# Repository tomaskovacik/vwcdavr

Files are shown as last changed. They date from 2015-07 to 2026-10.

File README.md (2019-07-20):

radio_emulator: arduino (ATMEGAX8 boards only) based vw/audi/skoda/seat radio emulator, I made this to revers eng. on vwcdpic and improve arduino version of CDchanger

 - emulate RADIO DataOut signal
 - receive and print CD changer responce to serial console

serial output is 9600

commands:
 
- next track button       =
- previous track button   -
- next CD                 ]
- previous CD             [
- play/stop               p
- CD1                     1
- CD2                     2
- CD3                     3
- CD4                     4
- CD5                     5
- CD6                     6
- seek forward            f
- seek rewind             r
- scan mode               s
- shuffle mode            l
- help                    h
 
connectios:

- DataOut -> arduino pin 12

- Clk     -> arduino pin 3

- DataIn  -> arduino pin 4 

CDC_emulator: arduino based cd changer emulator for vw/audi/skoda/seat radios, based on avr port of vwcdpic(see header of file for more info)

current status (see readme inside dir):
- tested with my old audi concert 1 radio
- version for 2 8bit timers, has, but if it still works is questionable:
- ARDUINO headphones support
- ARDUINO headphones single button support
- bluetooth support for modules with AT commands (ovc3860 based: XS3868, S3860M-S, BLK-MD-SPK-B), BK8000L - one way only, no feedback from module - TODO

vw_cd_changer_sniffer - sniffer for radio comunication

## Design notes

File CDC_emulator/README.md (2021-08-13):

Little talk/history: http://kovo-blog.blogspot.sk/2014/02/cd-changer-emulator.html

CDC_emulator: Arduino based CD changer emulator for VW/Audi/Skoda/Seat radios, based on AVR port of vwcdpic (see header of file for more info)

- Android headphones three button support, with cdc_arduino_ported_k9spud_vwcdpic_headphone_support (thx @domnulvlad)
- Android headphones single button support - dropped (if you wanna have this, take a look at history of .ino files and make patch, I do not have time to test this...)
- Bluetooth support for modules with serial comunication, not fully implemented yet 

port_of_shyd_version_for_mpd:
	Arduino port of SHYD version of his emulator, currently not used by me anymore ( http://dev.shyd.de/2013/09/avr-raspberry-pi-vw-beta-vag-cdc-faker/ )

cdc_arduino_ported_k9spud_vwcdpic:
- Arduino Uno/Duemilanove/Nano AVR port of vwcdpic project, initial work: http://forums.hackaday.com/viewtopic.php?f=3&t=123
- support for: ATmega328, ATmega328A, ATmega328P, ATmega328PA, ATmega324, ATmega324P, ATmega324A, ATmega324PA
- original vwcdpic PJRC controler support
- full SHYD mpd control support
- minimal Bluetooth support for BT with serial control support
- timer1 is used for timing incomming control data from radio pin DataOut, timer interrupt (ICP) is used
- timer2 is used for timing between pakcets and also 800us gap between bytes in packet
- timer0 is used for 10ms timing used for 50ms timing between packets and also for 1second count for play time count
- software serial us used to comunicate with BT over serial

Connections are defined by these defines:

for ATmegaXX8YY chips:
```
#define RADIO_COMMAND      PB0 //ICP
#define RADIO_COMMAND_DDR  DDRB
#define RADIO_COMMAND_PORT  PORTB
#define RADIO_COMMAND_PIN PINB
#define RADIO_CLOCK        PB5
#define RADIO_CLOCK_DDR    DDRB
#define RADIO_CLOCK_PORT  PORTB
#define RADIO_DATA         PB3
#define RADIO_DATA     DDB3
#define RADIO_DATA_DDR     DDRB
#define RADIO_DATA_PORT  PORTB
```

in Arduino world, it is:
```
 * RADIO PIN -> Arduino pin
 * 
 * DataOut   -> digital 8 (ICP1)
 * DataIn    -> digital 11(PB3)
 * Clock     -> digital 13(PB5)
 *
 * computer -> Arduino pin
 * serial TX -> digital 0 (PD0)
 * serial RX -> digital 1 (PD1)
```

for ATmegaXX4YY chips:
```
#define RADIO_COMMAND      PD6 //ICP 
#define RADIO_COMMAND_DDR  DDRD
#define RADIO_COMMAND_PORT  PORTD
#define RADIO_COMMAND_PIN PIND
#define RADIO_CLOCK        PB7
#define RADIO_CLOCK_DDR    DDRB
#define RADIO_CLOCK_PORT  PORTB
#define RADIO_DATA         PB5
#define RADIO_DATA_DDR     DDRB
#define RADIO_DATA_PORT  PORTB
```

in Arduino world, if my board is used (https://www.tindie.com/products/tomaskovacik/nanoxx4/) then this traslate to:
```
 * RADIO PIN -> Arduino pin
 *
 * DataOut   -> digital 8 (ICP1)
 * DataIn    -> digital 11(PB5)
 * Clock     -> digital 13(PB7)
 *
 * computer -> Arduino pin
 * serial TX -> digital 0 (PD0)
 * serial RX -> digital 1 (PD1)
```

cdc_arduino_ported_k9spud_vwcdpic_headphone_support:
- Support for: ATmega328, ATmega328A, ATmega328P, ATmega328PA, ATmega324, ATmega324P, ATmega324A, ATmega324PA
- Android three button headphones support or MP3 player buttons support
- Tested on Arduino Uno (ATmega328P)
- For more info, check the comment at the top of the file

Connections:
```
   UNO, Duemilanove, Nano ... ATmegaX8 base boards:
   RADIO PIN -> Arduino pin

   DataOut   -> digital 8 (PB0)
   DataIn    -> digital 11(PB5)
   Clock     -> digital 13(PB7)

   PC PIN    -> Arduino pin
   Serial TX -> digital 0 (PD0)
   Serial RX -> digital 1 (PD1)
   
   ANDROID support:
   NEXT button -> digital 5 (PD5)
   PLAY button -> digital 6 (PD6)
   PREV button -> digital 7 (PD7)
```

cdc_arduino_ported_k9spud_vwcdpic_just_8bit_timers:
same as previous, but use 2 8bit timers, mostly for ATTINY chips 
 - tested on ATmega328, ATmega8, ATtiny85
 - with ATtiny85 chip only serial output is used, no input (using tinydebug serial @ 9600) - BT support posible only if BT chip has default baudrate set to 9600
 - this version has support to control Android headphone simulating buttons on headphone jack (I do not remember if I tested it or not, sorry), also has single button support (single, double, triple click)

Connections:
```
   UNO, Duemilanove, Nano ... ATmegaX8 base boards:
   RADIO PIN -> Arduino pin

   DataOut   -> digital 2 (INT0)
   DataIn    -> digital 11(PB3)
   Clock     -> digital 13(PB5)

   PC PIN    -> Arduino pin
   Serial TX -> digital 0 (PD0)
   Serial RX -> digital 1 (PD1)

   ANDROID support:
   PREVIOUS BUTTON -> digital 7 (PD7)
   PLAY BUTTON -> digital 6 (PD6)
   NEXT BUTTON -> digital 5 (PD5)

   ATTINYx5 version:

   RADIO PIN -> ATTINYx5 PIN
   DataOut   -> 7 (INT0)
   DataIn    -> 6 (PB0)
   Clock     -> 5 (PB1)

   PC PIN    -> ATTINYx5 PIN
   Serial TX -> 2 (PB3) using tinydebug lib
   Serial RX -> not connected
```

   What you need to install:
   ATTinycore: https://github.com/SpenceKonde/ATTinyCore (supported directly in Arduino from version 1.6.3 via board manager)
   TinyDebugSerial from: https://github.com/jscrane/TinyDebugSerial (download and extract into libraries Arduino folder)

   select attiny25/45/85 board from tools-> board -> (ATTinyCore) ATtiny25/45/85
   select attiny85 from tools->chip->ATtiny85
   select internal 8Mhz from tools->Clock -> 8MHz (internal)

   to use digispark uncoment line //#define DIGISPARK
   then use 16MHz-noUSB settings 
   tested only with my ATTinyCore fork with Digispark support: https://github.com/tomaskovacik/ATTinyCore/

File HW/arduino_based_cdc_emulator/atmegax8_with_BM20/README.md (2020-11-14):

interactive bom:

https://tomaskovacik.github.io/vwcdavr/HW/arduino_based_cdc_emulator/atmegax8_with_BM20/bom01/ibom.html

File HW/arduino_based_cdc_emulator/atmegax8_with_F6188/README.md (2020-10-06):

link to ibom file on github.io pages:

https://tomaskovacik.github.io/vwcdavr/HW/arduino_based_cdc_emulator/atmegax8_with_F6188/bom/ibom.html

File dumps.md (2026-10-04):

## Dump pattern notes

Source files:
- `dumps/dump_cdc_real_changer.txt`
- `dumps/dump_cdc_real_changer_real_radio_audi_concert1.txt`

## Protocol encoding

CDC status packets are 8 bytes sent from the changer to the head unit over a clocked serial
bus.  The data line uses negative/inverted NRZ logic: a code bit of 0 drives the wire HIGH
and a code bit of 1 drives it LOW.  The sniffer reads pin-HIGH as 1, so the captured
(dump) byte equals `code_byte XOR 0xFF`.  Equivalently: `code_byte = dump_byte XOR 0xFF`.

### 8-byte packet layout (wire/dump values)

| Byte | Field | Notes |
|---|---|---|
| 0 | Frame start | Encodes state & ACK; emulator varies this by state |
| 1 | Disc | `disc_number = dump_byte XOR 0xBF`  (CD1=0x01, CD2=0x02 …) |
| 2 | Track | `track_number = dump_byte XOR 0xFF` |
| 3 | Minute | `minute = dump_byte XOR 0xFF` |
| 4 | Second | `second = dump_byte XOR 0xFF` |
| 5 | Scan/Mix flags | bit 5 (code) = Mix, bit 4 (code) = Scan; 0x00→wire 0xFF = no flags |
| 6 | Mute/State | Controls audio mute and player state (see below) |
| 7 | Frame end | Mirrors frame start state encoding |

### 4-byte radio command layout

| Byte | Value  | Notes |
|---|---|---|
| 1 | `0x53` | fixed header |
| 2 | `0x2C` | fixed header |
| 3 | cmd | command code, always a multiple of 4 |
| 4 | ~cmd | bitwise complement of byte 3 |

## Packet structure patterns

- Head unit command packets follow:
  - byte1 `0x53`
  - byte2 `0x2C`
  - byte3 command code
  - byte4 bitwise complement of byte3
- Frequent trailer/control command:
  - `532C14EB` appears very often (end command / next-cd follow-up behavior).

## Common command patterns from dumps

- Enable/disable:
  - `532CE41B` (ENABLE, common in one dump)
  - `532C08F7` (ENABLE MK, very common with Audi Concert 1 dump)
  - `532C10EF` (DISABLE)
- Navigation and mode:
  - `532C38C7` (SEEKFORWARD MK / inquiry-like transition)
  - `532CD827` (seek forward)
  - `532C58A7` (seek back)
  - `532C609F` / `532CE01F` (mix variants)
  - `532CA05F` (scan)
  - `532C30CF` (TP)

## State packets: emulator vs real changer comparison

The second dump (`dump_cdc_real_changer_real_radio_audi_concert1.txt`) contains captures
from both a real 6-disc changer and from the Arduino emulator (captured in different
sessions and concatenated).  Patterns with frame byte `0x34`/`0x3C` originate from the
emulator; patterns with `0xB4`/`0xBC` originate from the real changer.

### Idle state

| Source | Wire packet | Mute byte |
|---|---|---|
| Emulator | `74 BE FE FF FF FF 8F 7C` | `0x8F` |
| Real changer  | `B4 BF FF FF FF FF 8F BC` | `0x8F` |

**Mute byte matches (`0x8F`, code `0x70`).**  The frame bytes differ — the real changer
uses frame `0xB4`/`0xBC` for all states (constant), while the emulator changes the frame
byte per state.  Both are accepted by tested head units.

Disc byte: real changer starts at disc `0` (`0xBF`); emulator starts at disc `1` (`0xBE`).
This difference is cosmetic on head units that accept the first valid PLAY command.

### Play state

| Source | Wire packet | Mute byte | Frame |
|---|---|---|---|
| Emulator | `34 BE FE FF FF FF CF 3C` | `0xCF` | `34`/`3C`|
| Real changer  | `B4 BE FE FF FF FF 6F BC` | `0x6F` | `B4`/`BC`|

Differences:
- **Frame byte**: emulator `0x34`/`0x3C` (code `0xCB`/`0xC3`), real `0xB4`/`0xBC`
  (code `0x4B`/`0x43`).
- **Mute byte**: emulator `0xCF` (code `0x30`), real `0x6F` (code `0x90`).
  Bit 7 of the code differs: code `0x90 = 1001 0000` vs `0x30 = 0011 0000`.
  The comment in the code notes code `0x70` (wire `0x8F`) "mutes audio on Monsoon head
  units" during idle.  The real changer uses code `0x90` for play, which differs from both
  the emulator's play value (`0x30`) and the idle mute value (`0x70`).  The emulator is
  accepted by most tested head units with code `0x30`, but code `0x90` may be more
  compatible with Monsoon-type head units that use this byte for mute control.

### Disc announcement packets (during init/load)

During `StateInitPlay` the emulator sends disc-slot info bytes cycling from `0xD1` to
`0xD6` (wire `0x2E` to `0x29`).  These match the real changer's announce packets seen in
the dumps (e.g. `B4 2E 0 FF FF FF FF BC`, `B4 2D 0 FF FF ...`).  Encoding is correct.

## Response/frame behavior patterns

- Real changer streams repeated 8-byte status/display frames between command events.
- Around SCAN events, mode/status bytes often move to values consistent with scan flag
  enabled (for example, lines in the dump files that include `... EF ...` inside the
  8-byte response frame text).
- Dumps also show many interleaved, partially corrupted/noisy rows (capture timing/noise),
  so stable interpretation depends on repeated motifs rather than single lines.

## Code issues found during analysis

### Fixed bugs

1. **`cdButtonPushed` case 6 (functions.ino)**: case 6 incorrectly reset and returned
   `cd5pushed` instead of `cd6pushed`.  Fixed in the main variant.

2. **`Do_CD2` calls wrong argument (main .ino)**: `Do_CD2` called `cdButtonPushed(1)`
   instead of `cdButtonPushed(2)`, silently counting CD1 presses when CD2 is pressed.
   Fixed in the main variant.

3. **ATmega8 ISR assignment instead of comparison (main .ino, BK3254 variant)**: the
   ATmega8 `TIMER0_OVF` ISR used `=` (assignment) instead of `==` (comparison):
   ```c
   // BUG (before fix):
   if (counter_timer0_overflows = _TIMER0_OVERFLOW_COUNTS)
   // FIXED:
   if (counter_timer0_overflows == _TIMER0_OVERFLOW_COUNTS)
   ```
   With the assignment, `flag_50ms` fired on every overflow instead of every 50 ms,
   making the 50 ms timer fire ~50× too fast on ATmega8/ATmega128 targets.

### Noted discrepancies (not changed)

- **Play state mute byte**: emulator uses code `0x30` (wire `0xCF`); real changer uses
  code `0x90` (wire `0x6F`).  Most head units accept `0xCF`, but if audio stays muted
  during playback on a Monsoon-type head unit, changing `SendByte(0x30)` to
  `SendByte(0x90)` in `StatePlay` may help.
- **Frame bytes**: emulator encodes state in the frame byte (idle `0x8B`/`0x83`, play
  `0xCB`/`0xC3`); real changer uses a fixed frame byte (`0x4B`/`0x43`) for all states.
  This difference has not caused compatibility problems with tested radios.

## Practical implication for emulator tuning

- The strongest repeatable pattern tied to audible issues is SCAN-mode signaling.
- Suppressing SCAN indicator in emulator status packets is a reasonable first mitigation to test while keeping normal command parsing/ACK behavior.

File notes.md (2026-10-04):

## CDC emulator scan/mute test notes

### Context
- Investigated `CDC_emulator/cdc_arduino_ported_k9spud_vwcdpic` protocol handling and dumps in `dumps/`.
- Login/command framing looks correct (`53 2C <cmd> <~cmd>` and command byte multiple-of-4 checks).

### Observed issue
- Some radios intermittently enter CD scanning behavior and mute audio when emulator is active.
- In code, SCAN command (`Do_SCAN`, `0xA0`) previously toggled the SCAN indicator bit (`0x10`) in outgoing display/status mode byte.

### Change in this PR
- For `Do_SCAN`, keep `scan = FALSE` so outgoing packets do not set SCAN indicator bit.
- Command is still accepted and acknowledged; only scan-indicator signaling is suppressed.

### Why
- Dump patterns show real radios issuing SCAN-related commands, and historical comments in code already suggest scan signaling can cause mute on some units.
- This is a minimal risk change focused on avoiding the known mute path while preserving normal protocol flow.

### How to test
1. Flash updated sketch from `CDC_emulator/cdc_arduino_ported_k9spud_vwcdpic`.
2. Start playback and trigger operations that previously led to scan/mute (SCAN button, next/seek cycles, CD change).
3. Verify:
   - audio remains unmuted,
   - head unit still stays in CDC mode,
   - track/disc updates still work.
4. Compare with previous firmware if needed.

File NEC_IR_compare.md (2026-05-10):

# NEC IR Protocol vs VW CD-changer Protocol: Comparison

## Background

Investigation into whether an Arduino NEC IR library (e.g. IRremote, IRLib2) can replace the custom software used for the VW CD-changer (CDC) ↔ radio communication in this project.

## What the Custom SW Does

### TX (radio_emulator: Arduino pretends to be the radio, sends commands to CDC)

The `send_cmd()` / `shiftOutPulse()` functions in `radio_emulator.ino` manually bit-bang the DataOut line:

- 9 ms HIGH leader, 4.5 ms LOW space
- Each bit: 550 µs HIGH mark, then 540 µs (logic '0') or 1650 µs (logic '1') LOW space
- 4 bytes total per packet: `0x53 0x2C [cmd] [0xFF ^ cmd]`
- **Bit order: MSB first**

### RX (CDC emulator / sniffer: Arduino receives commands from real radio, responds as CDC)

The ISR in `cdc_arduino_ported_k9spud_vwcdpic.ino` uses Timer1 Input Capture to time LOW pulses on DataOut:

- Start bit: LOW > 3,200 µs
- Bit '1': LOW > 1,248 µs
- Bit '0': LOW > 256 µs
- Bits accumulated **MSB first** into a capture buffer

---

## Protocol Comparison Table

| Feature | NEC IR Library | VW Protocol | Compatible? |
|---|---|---|---|
| Leader mark | 9 ms | 9 ms | ✅ |
| Leader space | 4.5 ms | 4.5 ms | ✅ |
| Bit mark | 562.5 µs | ~550 µs (~2% off) | ✅ |
| Bit '0' space | 562.5 µs | ~540 µs (~4% off) | ✅ |
| Bit '1' space | 1687.5 µs | ~1650 µs (~2% off) | ✅ |
| Packet length | 32 bits | 32 bits | ✅ |
| **Bit order** | **LSB first** | **MSB first** | ❌ |
| Address validation | addr + ~addr = 0xFF | fixed 0x53 + 0x2C (0x53 + 0x2C ≠ 0xFF) | ❌ |
| Command validation | cmd + ~cmd = 0xFF | cmd + (0xFF ^ cmd) = 0xFF | ✅ |
| Physical medium | Modulated IR 38 kHz carrier → demodulator inverts signal | Direct wire (no carrier, no demodulation) | ❌ |
| Idle wire state | Library assumes demodulated: idle = HIGH | DataOut idle = LOW | ❌ |

---

## Analysis by Direction

### RX (receiving radio commands) — Feasible with adaptation

The timing tolerances of NEC libraries are typically ±20–30%, so the VW timing fits within NEC decoders. However, the following issues must be resolved:

1. **Polarity**: The VW DataOut wire is active-HIGH (mark = HIGH pulse), while an NEC demodulator output is active-LOW (mark = LOW = carrier present). The signal must be inverted — either via a transistor/NOT gate in hardware, or by configuring the library to use the opposite edge.
2. **Bit order**: After decoding, every received byte must be bit-reversed (`reverse_bits(byte)`) before use, since the library decodes LSB-first while the VW protocol is MSB-first.
3. **Address validation**: The library would decode `0x53 0x2C` as address + ~address, but `~0x53 = 0xAC ≠ 0x2C`, so **NEC address validation would reject all packets**. This check must be disabled or bypassed in the library.

### TX (sending radio commands) — Feasible with adaptation

Libraries like IRremote can send raw NEC timing. However:

1. **No IR carrier needed**: The 38 kHz carrier modulation must be disabled; the DataOut line must be driven directly.
2. **Bit order**: Each of the 4 bytes must be bit-reversed before passing to the library, or `sendRaw()` must be used with a manually constructed pulse array.
3. **Fixed address bytes**: The `0x53 0x2C` sync word must be sent as-is; a standard `sendNEC(address, command)` call would not produce the correct bit pattern without byte reversal.

---

## Practical Verdict

Using a standard NEC library **as-is will not work**. The protocol is close enough that it could be adapted **with the following modifications**:

1. **Hardware invert** the DataOut signal (one transistor or logic inverter between the Arduino pin and the VW bus).
2. **Bit-reverse** every byte before TX or after RX.
3. **Disable** NEC address-complement validation in the library's RX path.
4. For TX, use `sendRaw()` instead of `sendNEC()` to avoid the library imposing its own packet structure.

### Why the custom SW is preferred

The existing custom ISR-based approach is:
- Lean (~200 lines), no external dependencies
- Already verified against real hardware
- Handles the exact polarity, bit order, and sync-word format natively

A NEC library would add ~2–5 KB of flash, introduce 38 kHz carrier overhead that must be disabled, and still require all of the workarounds listed above. **The custom SW is the simpler and more reliable path for this use case.**

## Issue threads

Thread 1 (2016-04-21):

[Question] XS-3868 connect to arduino.

AYastrebov, 2016-04-21:
Hello, Tomas!

Nice work!
I've successfully flashed arduino pro mini and now have an AUX in my vw sony gamma 5.

I've purchased XS-3868 board and would like to use it in my system. But unfortunately, I can't figure out, which pins of XS-3868 should be connected to arduino board. Can you point me?

Thanks!

tomaskovacik, 2016-04-21:
Look in my hw repository. Kicad and there are modules with pinouts also schemarics for arduino and bluethooth

Sent from my Sony Xperia™ smartphone

---- Andrey Yastrebov wrote ----

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

Closed 2018-06-28.

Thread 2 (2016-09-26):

Atmega328

olii, 2016-09-26:
Does not work with Arduino nano(Atmega328) and Skoda Fabia Symphony.
I see data comming from head unit but on display it is "No CD Changer".

tomaskovacik, 2016-09-26:
I do not have skoda fabia with symphony.... but, which code? how you connect it to ? do you have pics ? did you connected it like  this https://github.com/tomaskovacik/hw/blob/master/kicad/arduino_based_cdc_emulator/connection_to_HU.png ?

olii, 2016-09-26:
no matter what project I used(https://github.com/tomaskovacik/vwcdavr/tree/master/CDC_emulator) , I read instructions in source how to connect to pins. As I wrote before, nano receives command from head unit, so I think connection is ok. However, Tx line on arduino(pin 13) is connected to LED, but I do not know if it can be the problem.

tomaskovacik, 2016-09-26:
Try vwcdpic if it's works if you can

Sent from my Sony Xperia™ smartphone

---- Oliver Nemček wrote ----

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

tomaskovacik, 2016-09-28:
hello, so I am on computer now, can you send me output of serial console of arduino? it should tel there if it understend what radio send to "changer" if there is problem it will not work. also pictures how do you wire it up please (idealy to my personal email adress). thats all I can do for you. Or I can send you one of wvcdpic units for free if it's works and you can try to fix vwcdavr code to works with skoda symphony?

olii, 2016-09-28:
I used this source I found somewhere at russian site. It works fine and that is all I want. I dont want advanced features, key  press, minutes and seconds ...

Maybe if you want, you can also use Spi library, because when I used my second arduino as logic analyzer, the output looked really bad. If I use this source, the output looks just fine.

Now I think I am going to build preamp from your scheme :)

https://gist.github.com/olii/56c874f41b649496672b34da8177ee7e

olii, 2016-09-28:
btw I think that emulator could decode radio commands, but radio couldnt because of some bug in the code

tomaskovacik, 2016-09-28:
if output look bad, that its problem with code/HW/freq, I will check it. Spi is ok when radio can handle the speed. I try it, but it's HW specific = not good for generic code which has to be ported to other mcus. Also code which you linked  work, but in some cases radio will not tolerate if you press button and cdchanger will not react as it should.

my be you did not configure it proparly. for basic functions you need to comment out mpd, bluetooth android stuff ...

just to clarify:
I'm not author of original C code, you can try original one, port it to arduino by your self and then tell me what I f*ck in it :) it will help other guys,  link is in coment of each code (www.mikrocontroller.net/attachment/31279/vwcdc.c).

Shyd version is just my port for shyd code for arduino, shyd version is what is on russian forum, just striped from other "mpd" stuff, or its my port of his work striped down.

tomaskovacik, 2018-06-29:
2ys inactivity, closing

kalabase, 2021-05-10:
after struggling for days mine finally went into CD Changer mode with Arduino IDE, UNO and a VW MK1 ZAR. thanks @tomaskovacik  if your have paypal for sponsor share link I can donate few bucks to show gratitude.
Next step is to connect audio signal
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

Closed 2018-06-29.

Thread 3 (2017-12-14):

Debugging 'dataerr' messages

justinvdk, 2017-12-14:
I've hooked up an Uno to my RCD 200. Everything seems to work okay (bit glitchy, but restarting radio + arduino usually does the trick).
To debug this I hooked up the serial monitor and it got spammed with `dataerr` messages.
Like so:
```
AudAudi Concert I Multimedia Gateway Ver.1.0c
RING
LIST2
80dataerr
Audi Concert I Multimedia Gateway Ver.1.0c
NEXT
LIST1
LIST2
dataerr
80Audi Concert I Multimedia Gateway Ver.1.0c
Audi Concert I Multimedia Gateway Ver.1.0c
Audi Concert I Multimedia Gateway Ver.1.0c
Audi Concert I Multimedia Gateway Ver.1.0c
LIST1
Audi Concert I Multimedia Gateway Ver.1.0c
LIST3
5300000000dataerr
LIST4
dataerr
80LIST5
400000dataerr
0000dataerr

```

Is this an actual error, or somewhat expected?

From the code the `dataerr` indicated a framing type data error, and also that "This should never happen on normal head unit sending 32 bit command strings with error free data".

I can't quite debug where the (seemingly) random numbers come from (`80`, `5300000000`, `400000`, etc). I.e. I can't find where in the code they are put into the txbuffer, via `EnqueueString` or otherwise.

Any ideas?

Ps. The CD / track buttons DO change the cd and track accordingly (cd1 - cd6 and TR01 - TR99).
Pps. Only thing hooked up are CLC, DATA_IN, DATA_OUT and ground. So without audio (Audio did work in a previous test, as long as the radio is in playing state, and I don't press buttons too quickly. If I do the radio stops playing).

EDIT:
I'm using the `cdc_arduino_ported_k9spud_vwcdpic_just_8bit_timers` version, I don't know if this matters

tomaskovacik, 2017-12-14:
hi, try regural version (without just_8bit_timers)..

regural version use 16bit timer, and also ICP1 which stopes timer and run ISR, 8bit version was originaly made to port it all to ATtiny85 mcus, it works but as you can see it need to by clean up or debug. there is lot of done in ISR ... which is not good as we know :)

more here:  http://kovo-blog.blogspot.sk/2015/06/vwcdpic-for-avr-arduino-and-attiny.html

justinvdk, 2017-12-14:
Ah I see. I figured that they would both work good and chose 8-bit only to have the 16-bit for myself to use (planning to interface with some other device).

Will try soon!

tomaskovacik, 2017-12-14:
bluetooth od dashboard ?:)

justinvdk, 2017-12-14:
I got a [SparkFun Purpletooth Jamboree](https://www.sparkfun.com/products/11924). I should be fine as it is possible to communicate over Serial.

I saw the TODO for AT commands, unfortunately I won't (can't) be helping with that :(

I WILL try to make it somewhat nice but I'm not very experienced in programming embedded stuff, so most is new to me.

justinvdk, 2017-12-14:
Switching to the "normal" version (with 16-bit timer) does not spew out errors (yay!).

But (for me, at least) the `capbuffer` isn't filled with anything (stays `000000000000000000000000`).

I can't investigate right now but will later. I'll close this issue as the original problem is not relevant anymore.

Closed 2017-12-14.

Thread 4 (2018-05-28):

arduino uno

JL01152, 2018-05-28:
I keep getting an error message of "PB0 was not declared in this scope." I am using an Arduino Uno and Arduino IDE I'm at a loss as to what the issue may be. Please Help.

tomaskovacik, 2018-05-28:
which sketch?

tomaskovacik, 2018-05-28:
I try all sketches in this repo, on arduino 1.8.5 everyone compile fine for arduino uno, closing

Closed 2018-05-28.

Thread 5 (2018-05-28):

Updated to Arduino 1.8.5 Still not compiling

JL01152, 2018-05-28:
Hi and thank you for your quick response. On my previous attempt I was using an outdated version of the Arduino IDE so I updated to 1.8.5 and now I'm getting the following error messages. This is for the  cdc_arduino_ported_k9spud_vwcdpic.ino file.

Arduino: 1.8.5 (Windows 7), Board: "Arduino/Genuino Uno"

C:\Users\WINDOW~1\AppData\Local\Temp\ccbR9Kq2.ltrans0.ltrans.o: In function `Init_VWCDC':

C:\Users\Windows7HD\Documents\cdc_arduino_ported_k9spud_vwcdpic/cdc_arduino_ported_k9spud_vwcdpic.ino:802: undefined reference to `ResetTime()'

C:\Users\Windows7HD\Documents\cdc_arduino_ported_k9spud_vwcdpic/cdc_arduino_ported_k9spud_vwcdpic.ino:804: undefined reference to `SetStateIdleThenPlay()'

C:\Users\Windows7HD\Documents\cdc_arduino_ported_k9spud_vwcdpic/cdc_arduino_ported_k9spud_vwcdpic.ino:813: undefined reference to `EnqueueString(unsigned char const*)'

C:\Users\Windows7HD\Documents\cdc_arduino_ported_k9spud_vwcdpic/cdc_arduino_ported_k9spud_vwcdpic.ino:815: undefined reference to `EnqueueString(unsigned char const*)'

C:\Users\Windows7HD\Documents\cdc_arduino_ported_k9spud_vwcdpic/cdc_arduino_ported_k9spud_vwcdpic.ino:817: undefined reference to `EnqueueString(unsigned char const*)'

C:\Users\Windows7HD\Documents\cdc_arduino_ported_k9spud_vwcdpic/cdc_arduino_ported_k9spud_vwcdpic.ino:819: undefined reference to `EnqueueString(unsigned char const*)'

C:\Users\Windows7HD\Documents\cdc_arduino_ported_k9spud_vwcdpic/cdc_arduino_ported_k9spud_vwcdpic.ino:856: undefined reference to `SendPacket()'

C:\Users\WINDOW~1\AppData\Local\Temp\ccbR9Kq2.ltrans0.ltrans.o: In function `main':

C:\Users\Windows7HD\Documents\cdc_arduino_ported_k9spud_vwcdpic/cdc_arduino_ported_k9spud_vwcdpic.ino:2156: undefined reference to `SetStateIdle()'

C:\Users\Windows7HD\Documents\cdc_arduino_ported_k9spud_vwcdpic/cdc_arduino_ported_k9spud_vwcdpic.ino:2183: undefined reference to `SetStatePlay()'

C:\Users\Windows7HD\Documents\cdc_arduino_ported_k9spud_vwcdpic/cdc_arduino_ported_k9spud_vwcdpic.ino:2190: undefined reference to `SetStateIdle()'

C:\Users\Windows7HD\Documents\cdc_arduino_ported_k9spud_vwcdpic/cdc_arduino_ported_k9spud_vwcdpic.ino:2206: undefined reference to `ResetTime()'

C:\Users\WINDOW~1\AppData\Local\Temp\ccbR9Kq2.ltrans0.ltrans.o: In function `CDC_Protocol':

C:\Users\Windows7HD\Documents\cdc_arduino_ported_k9spud_vwcdpic/cdc_arduino_ported_k9spud_vwcdpic.ino:1438: undefined reference to `SendPacket()'

C:\Users\Windows7HD\Documents\cdc_arduino_ported_k9spud_vwcdpic/cdc_arduino_ported_k9spud_vwcdpic.ino:1469: undefined reference to `EnqueueString(unsigned char const*)'

C:\Users\Windows7HD\Documents\cdc_arduino_ported_k9spud_vwcdpic/cdc_arduino_ported_k9spud_vwcdpic.ino:1471: undefined reference to `EnqueueString(unsigned char const*)'

C:\Users\Windows7HD\Documents\cdc_arduino_ported_k9spud_vwcdpic/cdc_arduino_ported_k9spud_vwcdpic.ino:1473: undefined reference to `EnqueueString(unsigned char const*)'

C:\Users\Windows7HD\Documents\cdc_arduino_ported_k9spud_vwcdpic/cdc_arduino_ported_k9spud_vwcdpic.ino:1529: undefined reference to `EnqueueString(unsigned char const*)'

C:\Users\Windows7HD\Documents\cdc_arduino_ported_k9spud_vwcdpic/cdc_arduino_ported_k9spud_vwcdpic.ino:1539: undefined reference to `EnqueueString(unsigned char const*)'

C:\Users\Windows7HD\Documents\cdc_arduino_ported_k9spud_vwcdpic/cdc_arduino_ported_k9spud_vwcdpic.ino:1545: undefined reference to `ScanCommandBytes()'

collect2.exe: error: ld returned 1 exit status

exit status 1
Error compiling for board Arduino/Genuino Uno.

This report would have more information with
"Show verbose output during compilation"
option enabled in File -> Preferences.

tomaskovacik, 2018-05-28:
please copy whole directory, not just one .ino file. functions.ino file is file which contain missing functions.

t.

JL01152, 2018-05-28:
Thanks a million. I was never gonna get that sorted. I successfully uploaded and will confirm functionality.
Closing.

Closed 2018-05-28.

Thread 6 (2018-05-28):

Cdc mode activated. No play function

JL01152, 2018-05-28:
I successfully compiled, uploaded and connected the arduino to audi symphony 2. It recognizes cdc1 track1 00:00 but does not emit sound from aux nor does it have play option. Is there sething I am missing?

tomaskovacik, 2018-05-28:
please comment out 85:
change
#define DISC_TRACK_NUMBER_FROM_MPD
to //#define DISC_TRACK_NUMBER_FROM_MPD

compile, upload and check what is on serial port please.

JL01152, 2018-05-28:
commented out line 85.

serial monitor:

Audi Concert I Multimedia Gateway Ver.1.0b
RING

JL01152, 2018-05-28:
solved by changing line 2156.

changed from SetStateIdle()
to SetStatePlay()
and it is working to play music from aux.

tomaskovacik, 2018-05-29:
thx! it should be probably used only with MPD control

t.

JL01152, 2018-05-30:
ok soi fried my arduino uno. I somehow shorted some pins while troubleshooting. I have uploaded the code to two different arduino pro minis and the unit does not change to cdc mode now when selecting CD.

Is there a way for me to confirm that I am receiving data from the headunit? Or are arduino pro minis incompatible?

Please help again.

JL01152, 2018-05-30:
i have 16mhz but i will check serial console. so far without unit powered upit keeps repeating the aforementioned messages without the RING.It did not do this with the uno

JL01152, 2018-06-07:
I found my issue. It turned out to be a wrong connection to the ground at the connector. The arduino would seem to power up and work properly but without the the ground it was never going to communicate with the unit. Thanks a million for your support. You are awesome.

Closed 2018-05-29.

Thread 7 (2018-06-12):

MPD Controls

JL01152, 2018-06-12:
Ok so I have been messing with the headphone jack on my galaxy s7 edge and I found that I can control the NEXT PREV PLAY/PAUSE functions with just shorting the the MIC ring to the GND ring.

Simulating Button Clicks (shorting to GND)
1 click = play/pause
2 quick clicks = NEXT track
3 quick clicks = PREV track
A 680ohm resistor to gnd simulates pressing the volume down key. ( Media if playing music, Ringtone volume if not playing music)

I have yet to find what other resistance values will do. I will try to incorporate these functions using a HEF4066 switch. Hopefully,

My question is. How can I take the command from the Head Unit buttons and have the arduino interpret them into IO functions?

Is this already included in your code?

tomaskovacik, 2018-06-12:
Heh, i dropped headphone button support in avr version when it was at arduino repository  , check history of project files here

https://github.com/tomaskovacik/arduino/commit/2bd01f2e5fd79624dc48ed7dc2a506906b061479

But really go for bluetooth, bk800l, bk3254 or microchip  bm20 module .....

tomaskovacik, 2018-06-13:
Schematics of headset with buttons :

https://forums.androidcentral.com/samsung-galaxy-s4/334540-galaxy-s4-headset-mic-button-wiring-schematic-pinout.html

Closed 2018-06-29.

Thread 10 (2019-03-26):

[audi concert 1] SCAN is blinking and muting sound

tomaskovacik, 2019-03-26:

tomaskovacik, 2019-03-26:
using version with 8bit timers

tomaskovacik, 2019-04-02:
HW problem ..

tomaskovacik, 2019-06-11:
crystal was not soldered properly :man_facepalming:

Closed 2019-04-02.

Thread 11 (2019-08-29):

single timer version

tomaskovacik, 2019-08-29:
Use timer probably 8bit one is fine, to tick and just increment variables

Based on dataout pin level set dataoutPinLevel to 1 or 0 , in uimer isr based on value of this var increment dataoutHighCount or dataoutLowCount variables.

Increment count varuable for 50ms flag (seconds tiking)

Increment variable for counting between bytes or between packets

Also will be nice if sending out bits will be timed by this counter, so 50us is probably best, bit timing is currently 40us so 50us is fine, clk value should be stored in variable( or we can read port bit, no?) And if we each tick simply invert it we have clock, then when this is low we czn set dataline and leave timer isr, if next time timer isr is fired  and we flip clock pin bit value ( so level) and it is high  we simply did not change dataline pin bit value and leave isr.

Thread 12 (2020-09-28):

No CDC detected using ATtiny85

lachaka, 2020-09-28:
Hi,
I can not simulate a CDC using the "cdc_arduino_ported_k9spud_vwcdpic_just_8bit_timers" version. On the serial monitor I got only the welcome text and the radio says " No CDC". The other version works fine, tested with atmega328.
Tried to slap Clk and Data in, but still no result.

tomaskovacik, 2020-09-28:
attiny85 at 8MHz ?

lachaka, 2020-09-28:
yep

tomaskovacik, 2020-09-28:
try this sketch on atmega328

lachaka, 2020-09-28:
Nothing happens, I even don't get "No CDC"

tomaskovacik, 2020-09-28:
try uncoment //_delay_loop_1(40); on lines 1134 and 1158

lachaka, 2020-09-28:
Now on atmega328 is working, on attiny is the same

tomaskovacik, 2020-09-28:
are you using HW pin 7,6 and 5 ?
   DataOut   -> 7 (INT0)
   DataIn    -> 6 (PB0)
   Clock     -> 5 (PB1)

lachaka, 2020-09-28:
Yes, but pin 5 is PB0 and 6 is PB1. Anyway after slapping still not success.

tomaskovacik, 2020-09-28:
yep, pb0 is 5, but it strange, anyway I cannot help you more right now, I will test it tomorow
t.

lachaka, 2020-09-28:
No worries. When the radio is powered off I got "00" dataerr and on powering it up another ones but a little bit different, if helpful.

tomaskovacik, 2020-09-29:
I just test code as it was  (no delay when clocking out data) and it works without problem, but I put defined 5microseconds delay there so it is same as 3timer version. Anyway,here is output:
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

tomaskovacik, 2020-09-29:
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

lachaka, 2020-09-29:
Now the CDC is detected and I got all six CDs, but after clicking two or three times any button the radio blocks and got dataerr in serial monitor. Maybe some other delays are needed.

tomaskovacik, 2020-09-29:
and what you did exactly? , as you can see I got to track 15 so -> 30 commands, got through.

you can play with CLK_DELAY value

lot of times, bad ground connection is problem. check that also

Closed 2020-09-30.

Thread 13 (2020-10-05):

CDC Emulator - sw and hw solution

maro159, 2020-10-05:
Hello,

at the beginning I would like to appreciate your work with VW CDC projects.

I am going to build complete CDC Emulator for VW Gamma IV with aux + bluetooth input for myself. I have been digging in your repositories for a bit.
I was going to use one of [these](https://github.com/tomaskovacik/hw/tree/master/kicad/arduino_based_cdc_emulator) projects, but I am not so sure if they are up-to-date (I also found it difficult to buy s3860m-s)

Would you mind answering a few questions?
-  Which HW design should I use?
-  Which BT audio module provides the best audio quality and has following parameters adjustable: (name, baudrate setting, connection sound adjustment)?
-  In case [these ones](https://github.com/tomaskovacik/vwcdavr/tree/master/HW/arduino_based_cdc_emulator/atmegax8_with_F6188) could be used, which SW file should I use to program uC?

Thanks in advance!

tomaskovacik, 2020-10-05:
do not use s3860m-s, I try it and have to replace it with BK8000L

BM20 is superb, but I only use it with stm32 (the project is in beta stage, but it will be opensource)

I add another one, which uses BK8000L, and it wok, I have few PCBs made for it, the only problem is that I did not swap serial lines, so some jumper wires are required: https://github.com/tomaskovacik/hw/tree/master/kicad/arduino_based_cdc_emulator/atmegax8_with_F-6188

maro159, 2020-10-05:
Thanks for your answer.

- What should _data_out_ pin be connected with? With radio _data_out_ or radio _data_in_?
- I see, that project for BK8000L does not have 5V voltage regulator? Is it better to have it on different PCB or it casued by PCB minimalization?
-  I also couldn't find _CDC_ENA_12V_ to _CDC_ENA_5V_ converter - isn't it neccesary anymore?
- Is this board ready to be programmed with one of [these](https://github.com/tomaskovacik/vwcdavr/tree/master/CDC_emulator)? Or should I edit it using BK8000L A/T command list?
- What can you say about BK8000L sound quality? Is it sufficient for daily listening or should I better wait for BM20 version?
- One of the projects you have recently added is using CS8645 instead of BK8000L - I guess this one is not tested yet, right?

Generally I am looking for a working CDC emulator with bt module, which supports microphone and controlling _play, pasue, skip, prev_ from the radio panel. I may pay for a one that works - assembled or kit, doesn't really matter.

I am really sorry for asking so many questions.

Thank you once again!

tomaskovacik, 2020-10-06:
hello,

no problem, it is not refined project, it was more like prototype, but it workout really good :)

- I added connection notes and fix name of 3pin connector, it is for 7805 switched power supply equivalent (AM1117 goes really hot and also it has huge quiescent current

- I have used cdc_ena_12V for "sw" switching on and off of emulator, but it is really not well documented, so using it as powersource and simply restart mcu is simpliest way, but I used it properly in my vwcdstm32 boards, so I will probably change this design one day and then there will be level shifeter from 12 to 5V

- bk8000L is cheaper then BM20 so this is a cheaper version of emulator with BT, I used it as immediete replacement of OVC board in my 1st prototype and using in in car for 2years, it hase litle bit shitty mic input, but again it is more problem of mic is my guess (I use 1$ mic from aliexpress :D )

if you have time, I can drop you some boards for module into the mail and you can test it :o) unfortunetly, I put all boards for ovc chips into recycle bin so no proper way to test it again. After few years of development of other boards, I am preaty sure problem was the design of the board

regarding SW, I have special version, but it has simply changed pins for dataout,datain and clk, and has changed  output strings on serial line to AT commands, I use this SW as base:

https://github.com/tomaskovacik/vwcdavr/tree/master/CDC_emulator/cdc_arduino_ported_k9spud_vwcdpic_just_8bit_timers

#define RADIO_COMMAND      PB0 //ICP
#define RADIO_COMMAND_DDR  DDRB
#define RADIO_COMMAND_PORT  PORTB
#define RADIO_COMMAND_PIN PINB
#define RADIO_CLOCK        PD4//PB5
#define RADIO_CLOCK_DDR    DDRD//DDRB
#define RADIO_CLOCK_PORT  PORTD//PORTB
#define RADIO_DATA         PC3//PB3
#define RADIO_DATA_DDR     DDRC//DDRB
#define RADIO_DATA_PORT  PORTC//PORTB

const uint8_t sDATAERR[] PROGMEM = "";
const uint8_t sOVERFLOW[] PROGMEM = "";
const uint8_t sMDISABLE[] PROGMEM = "AT+MC\r\n";
const uint8_t sMENABLE[] PROGMEM = "AT+MA\r\n";
const uint8_t sMINQUIRY[] PROGMEM = "";
const uint8_t sPRV_LIST[] PROGMEM = "AT+MA\r\n";
const uint8_t sNXT_LIST[] PROGMEM = "AT+MA\r\n";
const uint8_t sLIST1[] PROGMEM = "AT+MA\r\n";
const uint8_t sLIST2[] PROGMEM = "AT+MA\r\n";
const uint8_t sLIST3[] PROGMEM = "AT+MA\r\n";
const uint8_t sLIST4[] PROGMEM = "AT+MA\r\n";
const uint8_t sLIST5[] PROGMEM = "AT+MA\r\n";
const uint8_t sLIST6[] PROGMEM = "AT+MA\r\n";
const uint8_t sRANDOM[] PROGMEM = "";
const uint8_t sPLAY[] PROGMEM = "AT+MA\r\n";
const uint8_t sSCAN[] PROGMEM = "";
const uint8_t sSTOP[] PROGMEM = "AT+MC\r\n";
const uint8_t sNEXT[] PROGMEM = "AT+MD\r\n";
const uint8_t sPREVIOUS[] PROGMEM = "AT+ME\r\n";
const uint8_t sRING[] PROGMEM = "";
const uint8_t sIDENTIFY[] PROGMEM = "";
const uint8_t sNEWLINE[] PROGMEM = "";
const uint8_t sDASH[] PROGMEM = "";
const uint8_t sHEX[] PROGMEM = "";
const uint8_t sVERSION[] PROGMEM = "";

tomaskovacik, 2020-10-06:
HW part moved to this repository https://github.com/tomaskovacik/vwcdavr/tree/master/HW/arduino_based_cdc_emulator

maro159, 2020-10-07:
Thank you.
Can I use _CDC_ENA_ (+12V cd changer supply switched by radio) to power the whole circuit? I would connect both _+12V_ and _CDC_ENA_12V_ pins to radio switched +12V available on radio C connector. I think current of the circuit with atmega, bt module and amplifier won't exceed max current of that radio output. What do you think?

I would appreciate getting some PCBs from you and yes, I have some time to test it and write about my results. How can I DM you?

tomaskovacik, 2020-10-07:
yes you can drive the whole circuit from switched 12V, but I cannot say if all radios have the same current capability, old Audi concert/chorus1 have a chip which max at 3A
you can drop me email at nail@nodomain.sk

Closed 2020-10-17.

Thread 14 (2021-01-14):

help in making pcb

Yyybrzuszek, 2021-01-14:
Hi, I want to make your protek for my car with the bt F6188 module, but I can't open KiCad files

tomaskovacik, 2021-01-14:
try this: https://kicad-downloads.s3.cern.ch/index.html?prefix=windows/nightly/

Closed 2021-01-15.

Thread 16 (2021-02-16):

Serial Print and theyre meanings

DaMusikant, 2021-02-16:
Hi,
you already helped me lot but I'm again stuck in the middle of the code.

The problem is, that the Arduino is sending some messages that are not encodible. Every third message I got a "007904FB" if I am in CD Changer mode with my radio and "007901FE" if I am not in CD Changer mode.

If I press down the button to go into CD Changer mode I got

`MENABLE007904FBMENABLE007904FBMENABLEMENABLE007904FBMENABLE`

I think those are current status updates. But the problem is that they are also going in between the main messages like `007904FBLIST2`

For my purpose I don't need those messages but I didn't found any possibility to disable them.

Can you help me?

Thank you and greetings

tomaskovacik, 2021-02-16:
commands are decoded here: https://github.com/tomaskovacik/vwcdavr/blob/13e3b846cec330603b42a533d24978976087eb6e/CDC_emulator/cdc_arduino_ported_k9spud_vwcdpic/cdc_arduino_ported_k9spud_vwcdpi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

but only in 1st byte is 0x53 2nd is 0x2c :+1:
https://github.com/tomaskovacik/vwcdavr/blob/13e3b846cec330603b42a533d24978976087eb6e/CDC_emulator/cdc_arduino_ported_k9spud_vwcdpic/functions.ino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

put some debug info there and check if it is dumped in ScanCommandBytes() with DumpFullCommand() or it is dumped in DecodeCommand()

but I think it is wrong command send by radio and ScanCommandBytes() did not understand it, because DecodeCommand() should mark dash before unknown cmd and newline after this cmd.

DaMusikant, 2021-08-05:
Hi, after a long period of try and error I still stuck. I'm new to coding and all that stuff, thats properly the main problem ;)
I tried to insert some debug infos but nothing changed, or the whole code was getting faulty.
To my understand, the ScanCommandBytes checks if the commands are correct. If not it is waiting until a good one is arriving. Right?

Another idea (?): It is working almost fine, the only problem are those commands. So if it is possible to just throw them into the bin and use only the ones, that we are understand, it would work fine. But on the search for this possibility I got also stuck.

Can you help another time? Thank you

tomaskovacik, 2021-08-05:
standard code should output each 10s  on the serial terminal "Audi Concert I Multimedia Gateway Ver."

did you get this text?

DaMusikant, 2021-08-05:
I get the text only every startup of the whole system.
The message pops up every 4th second btw, no matter in which mode (CDC or FM) I am

tomaskovacik, 2021-08-05:
That is ok i have to look into itOn 5 Aug 2021 18:04, DaMusikant ***@***.***> wrote:
I get the text only every startup of the whole system.
The message pops up every 4th second btw, no matter in which mode (CDC or FM) I am

—You are receiving this because you commented.Reply to this email directly, view it on GitHub, or unsubscribe.

DaMusikant, 2021-08-05:
Thank you very much :)

DaMusikant, 2021-08-05:
Hi, I found another method to avoid the problem, just ignore the commands on the other end of the serial end. But thank you very much :)

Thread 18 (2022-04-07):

Question: Receiving media keys/ multi stearing commands and pass to CDC emulator

istals, 2022-04-07:
Hey!

I have a question,

Is there a possibility to get prev/next commands from the head unit and multi steering next/prev track signals pass to CDC emulators?

tomaskovacik, 2022-04-07:
these?

https://github.com/tomaskovacik/vwcdavr/blob/eaf4728656153876310d7062e409dd500cb984b5/CDC_emulator/cdc_arduino_ported_k9spud_vwcdpic/cdc_arduino_ported_k9spud_vwcdpi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

tomaskovacik, 2022-04-07:
what exactly do you need to do with them?  if you press button on MFSW or on radio then emulator will change track

tomaskovacik, 2022-04-07:
is it working without your changes ?

istals, 2022-04-07:
Regarding this, how could I test that these buttons are working and I'm receiving those bytes?
DUMPMODE and DUMPMODE2 must be enabled?

istals, 2022-04-07:
No, not working no data from head unit

tomaskovacik, 2022-04-07:
arduino pin 8 is connected to dataout on the radio?

   RADIO PIN -> arduino pin
   DataOut   -> digital 8 (ICP1)
   DataIn    -> digital 11(PB3) (10 for atmega328PB)
   Clock     -> digital 13(PB5)

tomaskovacik, 2022-04-07:
you should see some commands on serial at startup of radio, mainly disable and enable, depends on state in which radio started

istals, 2022-04-07:
Looks like my head unit is not providing any data, closing

tomaskovacik, 2022-04-07:
radio must be coded to have cdc enabled, try it

http://wiki.ross-tech.com/wiki/index.php/Audi_Radio_Generation_I#Coding

Closed 2022-04-07.

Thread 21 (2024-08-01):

ATtiny 2313 Support

tengzl33t, 2024-08-01:
Hello, can it be ported to ATtiny 2313 with Blaupunkt MCD RNS button support added?
There is already existing firmware for it, but without button support and no source code available.

RNS button actions -> ATtiny -> Bluetooth module button inputs

Thank you.
[Emulator MCD.zip](https://github.com/user-attachments/files/16454051/Emulator.MCD.zip)

tomaskovacik, 2024-08-05:
[attiny2313_4313.zip](https://github.com/user-attachments/files/16491360/attiny2313_4313.zip)
I did a quick look at datasheet and add som defines to select proper registers:
```
|| defined(__AVR_ATtiny4313__)
```
try attached code, pin outputs are defined here:

```
#if defined(__AVR_ATtiny85__) || defined(__AVR_ATtiny45__) || defined(__AVR_ATtiny4313__)
#define RADIO_COMMAND      PB2
#define RADIO_COMMAND_DDR  DDRB
#define RADIO_COMMAND_PORT PORTB
#define RADIO_COMMAND_PIN  PINB
#define RADIO_CLOCK        PB1
#define RADIO_CLOCK_DDR    DDRB
#define RADIO_CLOCK_PORT   PORTB
#define RADIO_CLOCK_PIN    PINB
#define RADIO_DATA         PB0
#define RADIO_DATA_DDR     DDRB
#define RADIO_DATA_PORT    PORTB
```

tengzl33t, 2024-08-12:
Unfortunately, I was not able to get any replies from some of the potential devs of that firmware. So looks like it is not possible to get any sources now.

Is it possible to maintain the same pins in use, like how they are used in the project I sent in the first message to not rebuild the board?

I have also mentioned forwarding the radio button actions to the Bluetooth module. I think this could be done with converting the codes got from radio to 3.3V High levels on desired pins.

Thank you.

tomaskovacik, 2024-08-13:
well, I changes pins on attached firmware, you should really do it your self, it was easy as changing 16 pins definitions which I wrote you in prev. comment ...
regarding controlling bluetooth module, that is out of my reach, I do not know which module you have, I do not have that radio ....  so it is up to you :)
[firm.zip](https://github.com/user-attachments/files/16596988/firm.zip)

Closed 2024-11-02.

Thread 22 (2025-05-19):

Radio emulator with CX-CV1811F

krcenov, 2025-05-19:
Hello, im having issues making this CD Changer do anything.....
Im running a modified version of your radio emulator to work with MEGA 2560
This is the console output
`VW Group Radio Emulator
power on                o
change cd               c
next track button       =
previous track button   -
next CD                 ]
previous CD             [
play/stop               p
CD1                     1
CD2                     2
CD3                     3
CD4                     4
CD5                     5
CD6                     6
CD7                     7
CD8                     8
CD9                     9
TP                      t
seek forward            f
seek rewind             r
scan mode               s
shuffle 1cd             l
shuffle 6cd             k
help                    h
power on
---------------------------------------------
53 2C A4 5B
---------------------------------------------
---------------------------------------------
53 2C 14 EB
---------------------------------------------
toggle scan
---------------------------------------------
53 2C A0 5F
---------------------------------------------
play
---------------------------------------------
53 2C E4 1B
---------------------------------------------
---------------------------------------------
53 2C 14 EB
---------------------------------------------
cd2
---------------------------------------------
53 2C 8C 73
---------------------------------------------
---------------------------------------------
53 2C 38 C7
---------------------------------------------
cd2
---------------------------------------------
53 2C 8C 73
---------------------------------------------
---------------------------------------------
53 2C 38 C7
---------------------------------------------
cd2
---------------------------------------------
53 2C 8C 73
---------------------------------------------
---------------------------------------------
53 2C 38 C7
---------------------------------------------
cd2
---------------------------------------------
53 2C 8C 73
---------------------------------------------
---------------------------------------------
53 2C 38 C7
---------------------------------------------
cd2
---------------------------------------------
53 2C 8C 73
---------------------------------------------
---------------------------------------------
53 2C 38 C7
---------------------------------------------
cd2
---------------------------------------------
53 2C 8C 73
---------------------------------------------
---------------------------------------------
53 2C 38 C7
---------------------------------------------
cd2
---------------------------------------------
53 2C 8C 73
---------------------------------------------
---------------------------------------------
53 2C 38 C7
---------------------------------------------
cd2
---------------------------------------------
53 2C 8C 73
---------------------------------------------
---------------------------------------------
53 2C 38 C7
---------------------------------------------
cd2
---------------------------------------------
53 2C 8C 73
---------------------------------------------
---------------------------------------------
53 2C 38 C7
---------------------------------------------
cd2
---------------------------------------------
53 2C 8C 73
---------------------------------------------
---------------------------------------------
53 2C 38 C7
---------------------------------------------
cd2
---------------------------------------------
53 2C 8C 73
---------------------------------------------
---------------------------------------------
53 2C 38 C7
---------------------------------------------
cd2
---------------------------------------------
53 2C 8C 73
---------------------------------------------
---------------------------------------------
53 2C 38 C7
---------------------------------------------
cd2
---------------------------------------------
53 2C 8C 73
---------------------------------------------
---------------------------------------------
53 2C 38 C7
---------------------------------------------
cd2
---------------------------------------------
53 2C 8C 73
---------------------------------------------
---------------------------------------------
53 2C 38 C7
---------------------------------------------
cd2
---------------------------------------------
53 2C 8C 73
---------------------------------------------
---------------------------------------------
53 2C 38 C7
---------------------------------------------
cd2
---------------------------------------------
53 2C 8C 73
---------------------------------------------
---------------------------------------------
53 2C 38 C7
---------------------------------------------
cd2
---------------------------------------------
53 2C 8C 73
---------------------------------------------
---------------------------------------------
53 2C 38 C7
---------------------------------------------
cd2
---------------------------------------------
53 2C 8C 73
---------------------------------------------
---------------------------------------------
53 2C 38 C7
---------------------------------------------
next cd
---------------------------------------------
53 2C 38 C7
---------------------------------------------
---------------------------------------------
53 2C 14 EB
---------------------------------------------
next cd
---------------------------------------------
53 2C 38 C7
---------------------------------------------
---------------------------------------------
53 2C 14 EB
---------------------------------------------
next cd
---------------------------------------------
53 2C 38 C7
---------------------------------------------
---------------------------------------------
53 2C 14 EB
---------------------------------------------
next cd
---------------------------------------------
53 2C 38 C7
---------------------------------------------
---------------------------------------------
53 2C 14 EB
---------------------------------------------
next cd
---------------------------------------------
53 2C 38 C7
---------------------------------------------
---------------------------------------------
53 2C 14 EB
---------------------------------------------
next cd
---------------------------------------------
53 2C 38 C7
---------------------------------------------
---------------------------------------------
53 2C 14 EB
---------------------------------------------
next cd
---------------------------------------------
53 2C 38 C7
---------------------------------------------
---------------------------------------------
53 2C 14 EB
---------------------------------------------
next cd
---------------------------------------------
53 2C 38 C7
---------------------------------------------
---------------------------------------------
53 2C 14 EB
---------------------------------------------
next cd
---------------------------------------------
53 2C 38 C7
---------------------------------------------
---------------------------------------------
53 2C 14 EB
---------------------------------------------
next cd
---------------------------------------------
53 2C 38 C7
---------------------------------------------
---------------------------------------------
53 2C 14 EB
---------------------------------------------
`

and this is the modified version, am i skipping something?
`// VW Group Radio Emulator for CD Changer (CX-CV1811F/1820L or CX-CA1821/1822L)
// Runs on Arduino Mega 2560
// Emulates radio sending 4-byte commands and receiving 8-byte responses

#define DataOut 22  // CN701 Pin 1 (CD Data, output)
#define Clk 23      // CN701 Pin 2 (CD Clock, input for response)
#define DataIn 24   // CN701 Pin 1 (CD Data, input for response, shared with DataOut)
#define ClkInt 4    // Mega interrupt for pin 23 (INT4)

// Command definitions
#define CDC_END_CMD 0x14
#define CDC_END_CMD2 0x38
#define CDC_PLAY 0xE4
#define CDC_STOP 0x10  // Go to radio mode
#define CDC_NEXT 0xF8
#define CDC_PREV 0x78
#define CDC_SEEK_FWD 0xD8
#define CDC_SEEK_RWD 0x58
#define CDC_CD1 0x0C
#define CDC_CD2 0x8C
#define CDC_CD3 0x4C
#define CDC_CD4 0xCC
#define CDC_CD5 0x2C
#define CDC_CD6 0xAC
#define CDC_CD7 0x6C
#define CDC_CD8 0xEC
#define CDC_CD9 0x1C
#define CDC_SCAN 0xA0
#define CDC_SFL 0x60
#define CDC_PLAY_NORMAL 0x08
#define CDC_PREV_CD 0x18
#define CDC_RANDOM6CD 0xE0
#define CDC_POWERON 0xA4
#define CDC_CDCHANGE 0x01
#define CDC_TP 0x30

// Global variables
int cd = 0;
int tr = 0;
int minutes = 0;
int sec = 0;
int mode = 0;
int play = 0;
volatile uint64_t cmd = 0;
volatile uint64_t prev_cmd = 0;
volatile int cmdbit = 0;
volatile uint8_t newcmd = 0;
int incomingByte = 0;
int verbose = 1;

void setup() {
  // Initialize pins
  pinMode(DataOut, OUTPUT);
  digitalWrite(DataOut, LOW);
  pinMode(Clk, INPUT);
  pinMode(DataIn, INPUT);

  // Initialize serial
  Serial.begin(9600);
  Serial.println("VW Group Radio Emulator");

  // Configure Timer1 for packet reset (44.8 ms timeout)
  cli(); // Disable interrupts
  TCCR1A = 0;
  TCCR1B = 0;
  TCCR1C = 0;
  TCNT1 = 0;
  TIMSK1 |= _BV(OCIE1A);
  OCR1A = 700; // 700 * 64 µs = 44.8 ms
  TCCR1B |= _BV(CS12) | _BV(CS10); // Prescaler 1024 (64 µs tick)
  sei(); // Enable interrupts

  // Attach interrupt for Clk (INT4 on Mega pin 23)
  attachInterrupt(digitalPinToInterrupt(Clk), readDataIn, FALLING);
}
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
krcenov, 2025-05-19:
[1J6035111_SM_VW.pdf](https://github.com/user-attachments/files/20319623/1J6035111_SM_VW.pdf)

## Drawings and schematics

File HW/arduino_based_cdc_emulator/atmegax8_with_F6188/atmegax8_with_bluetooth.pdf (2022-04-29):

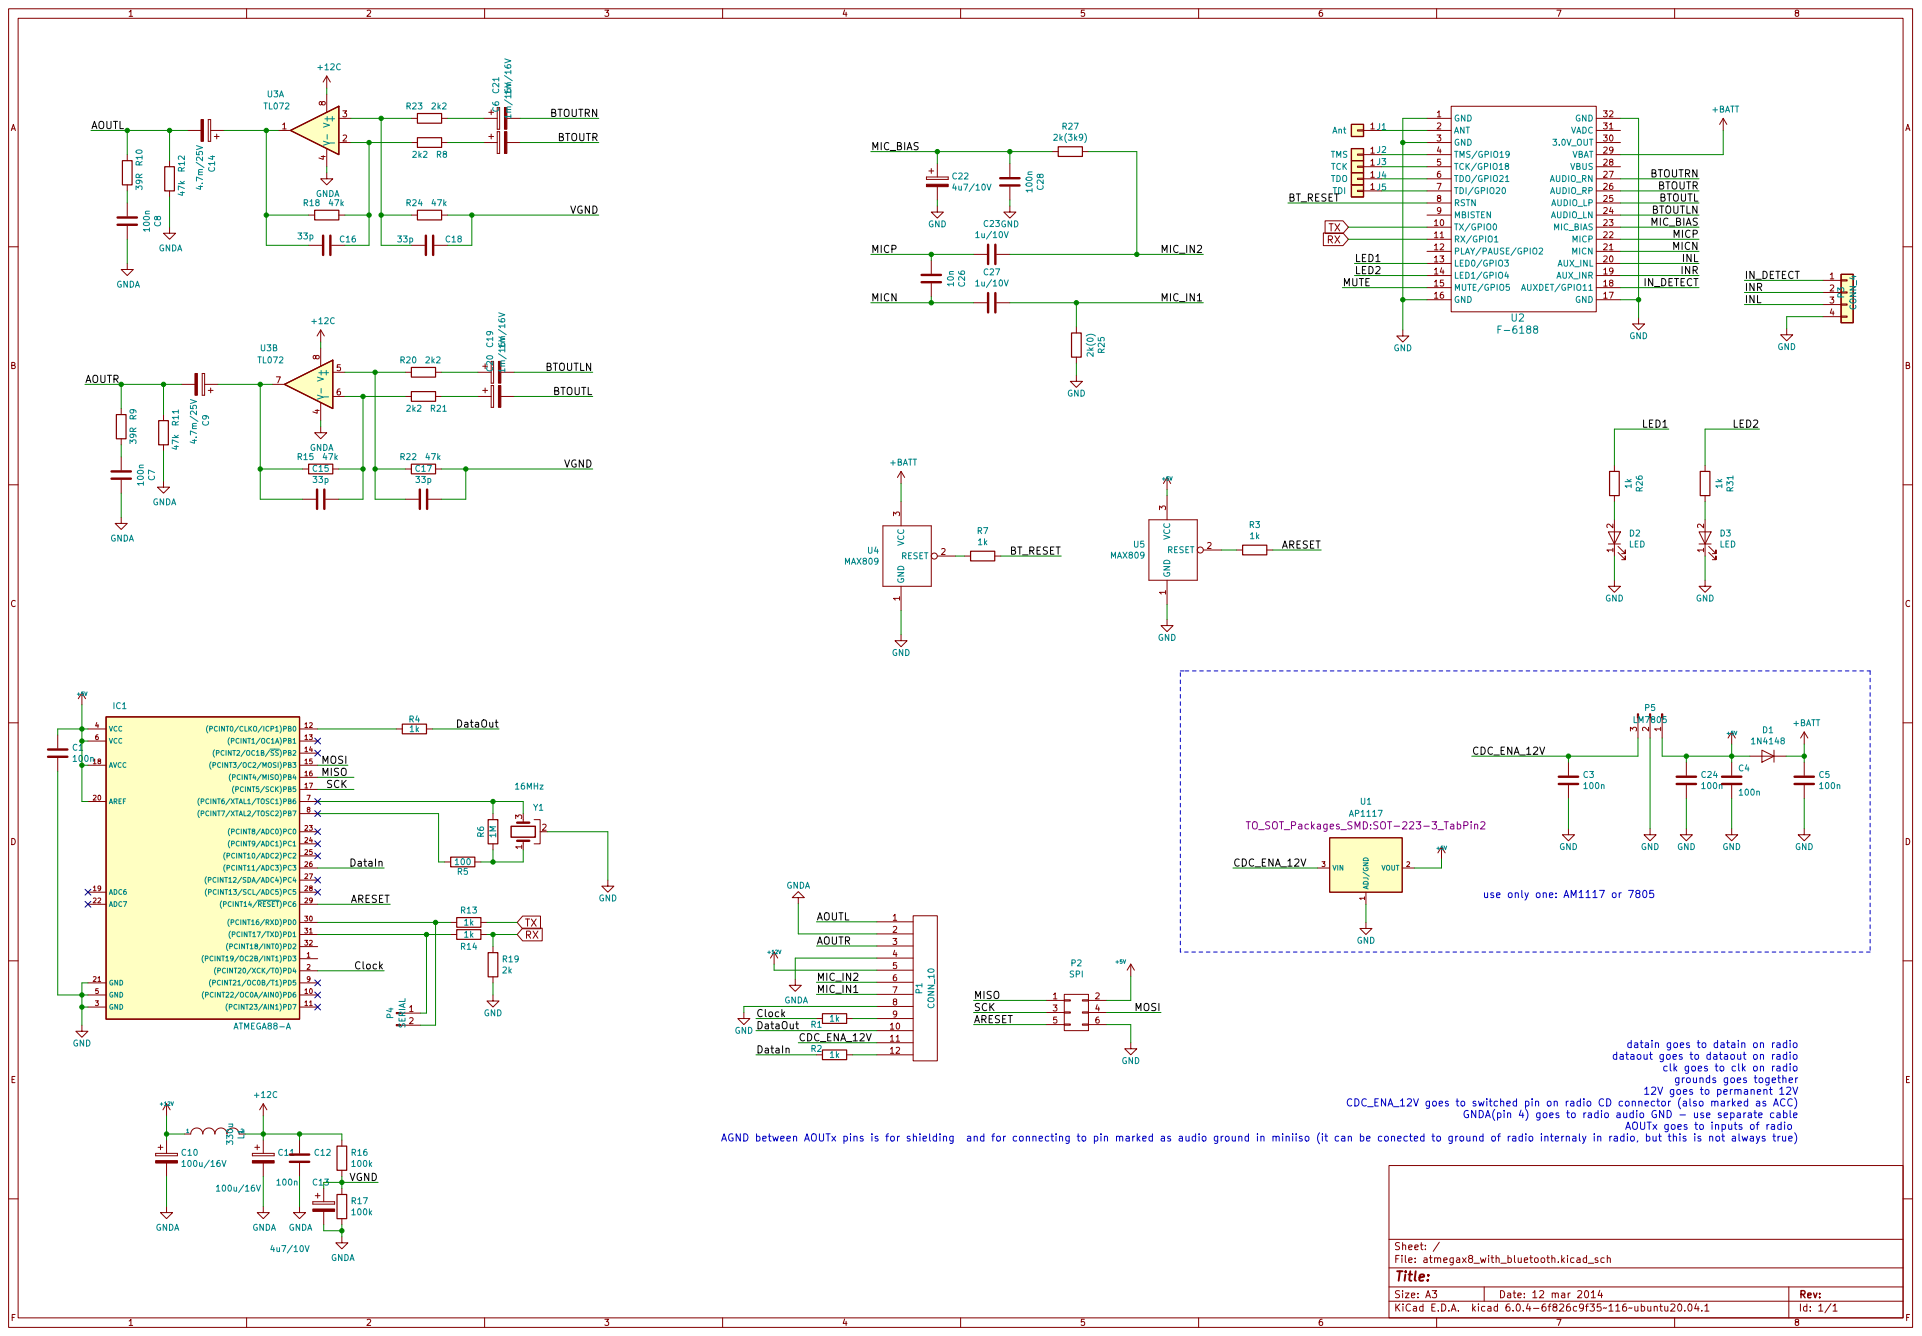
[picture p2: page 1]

3 U5 MAX809 GND 1 TX/GPIO0 10 RX/GPIO1 11 PLAY/PAUSE/GPIO2 12

LED2

IN_DETECT

INL | 3

use only one: AM1117 or 7805

datain goes to datain on radio
dataout goes to dataout on radio

clk goes to clk on radio
grounds goes together
12V goes to permanent 12V

CDC_ENA_12V goes to switched pin on radio CD connector (also marked as ACC)

GNDA(pin 4) goes to radio audio GND - use separate cable

AOUTx goes to inputs of radio

AGND between AOUTx pins is for shielding and for connecting to pin marked as audio ground in miniiso (it can be conected to ground of radio internaly in radio, but this is not always true)

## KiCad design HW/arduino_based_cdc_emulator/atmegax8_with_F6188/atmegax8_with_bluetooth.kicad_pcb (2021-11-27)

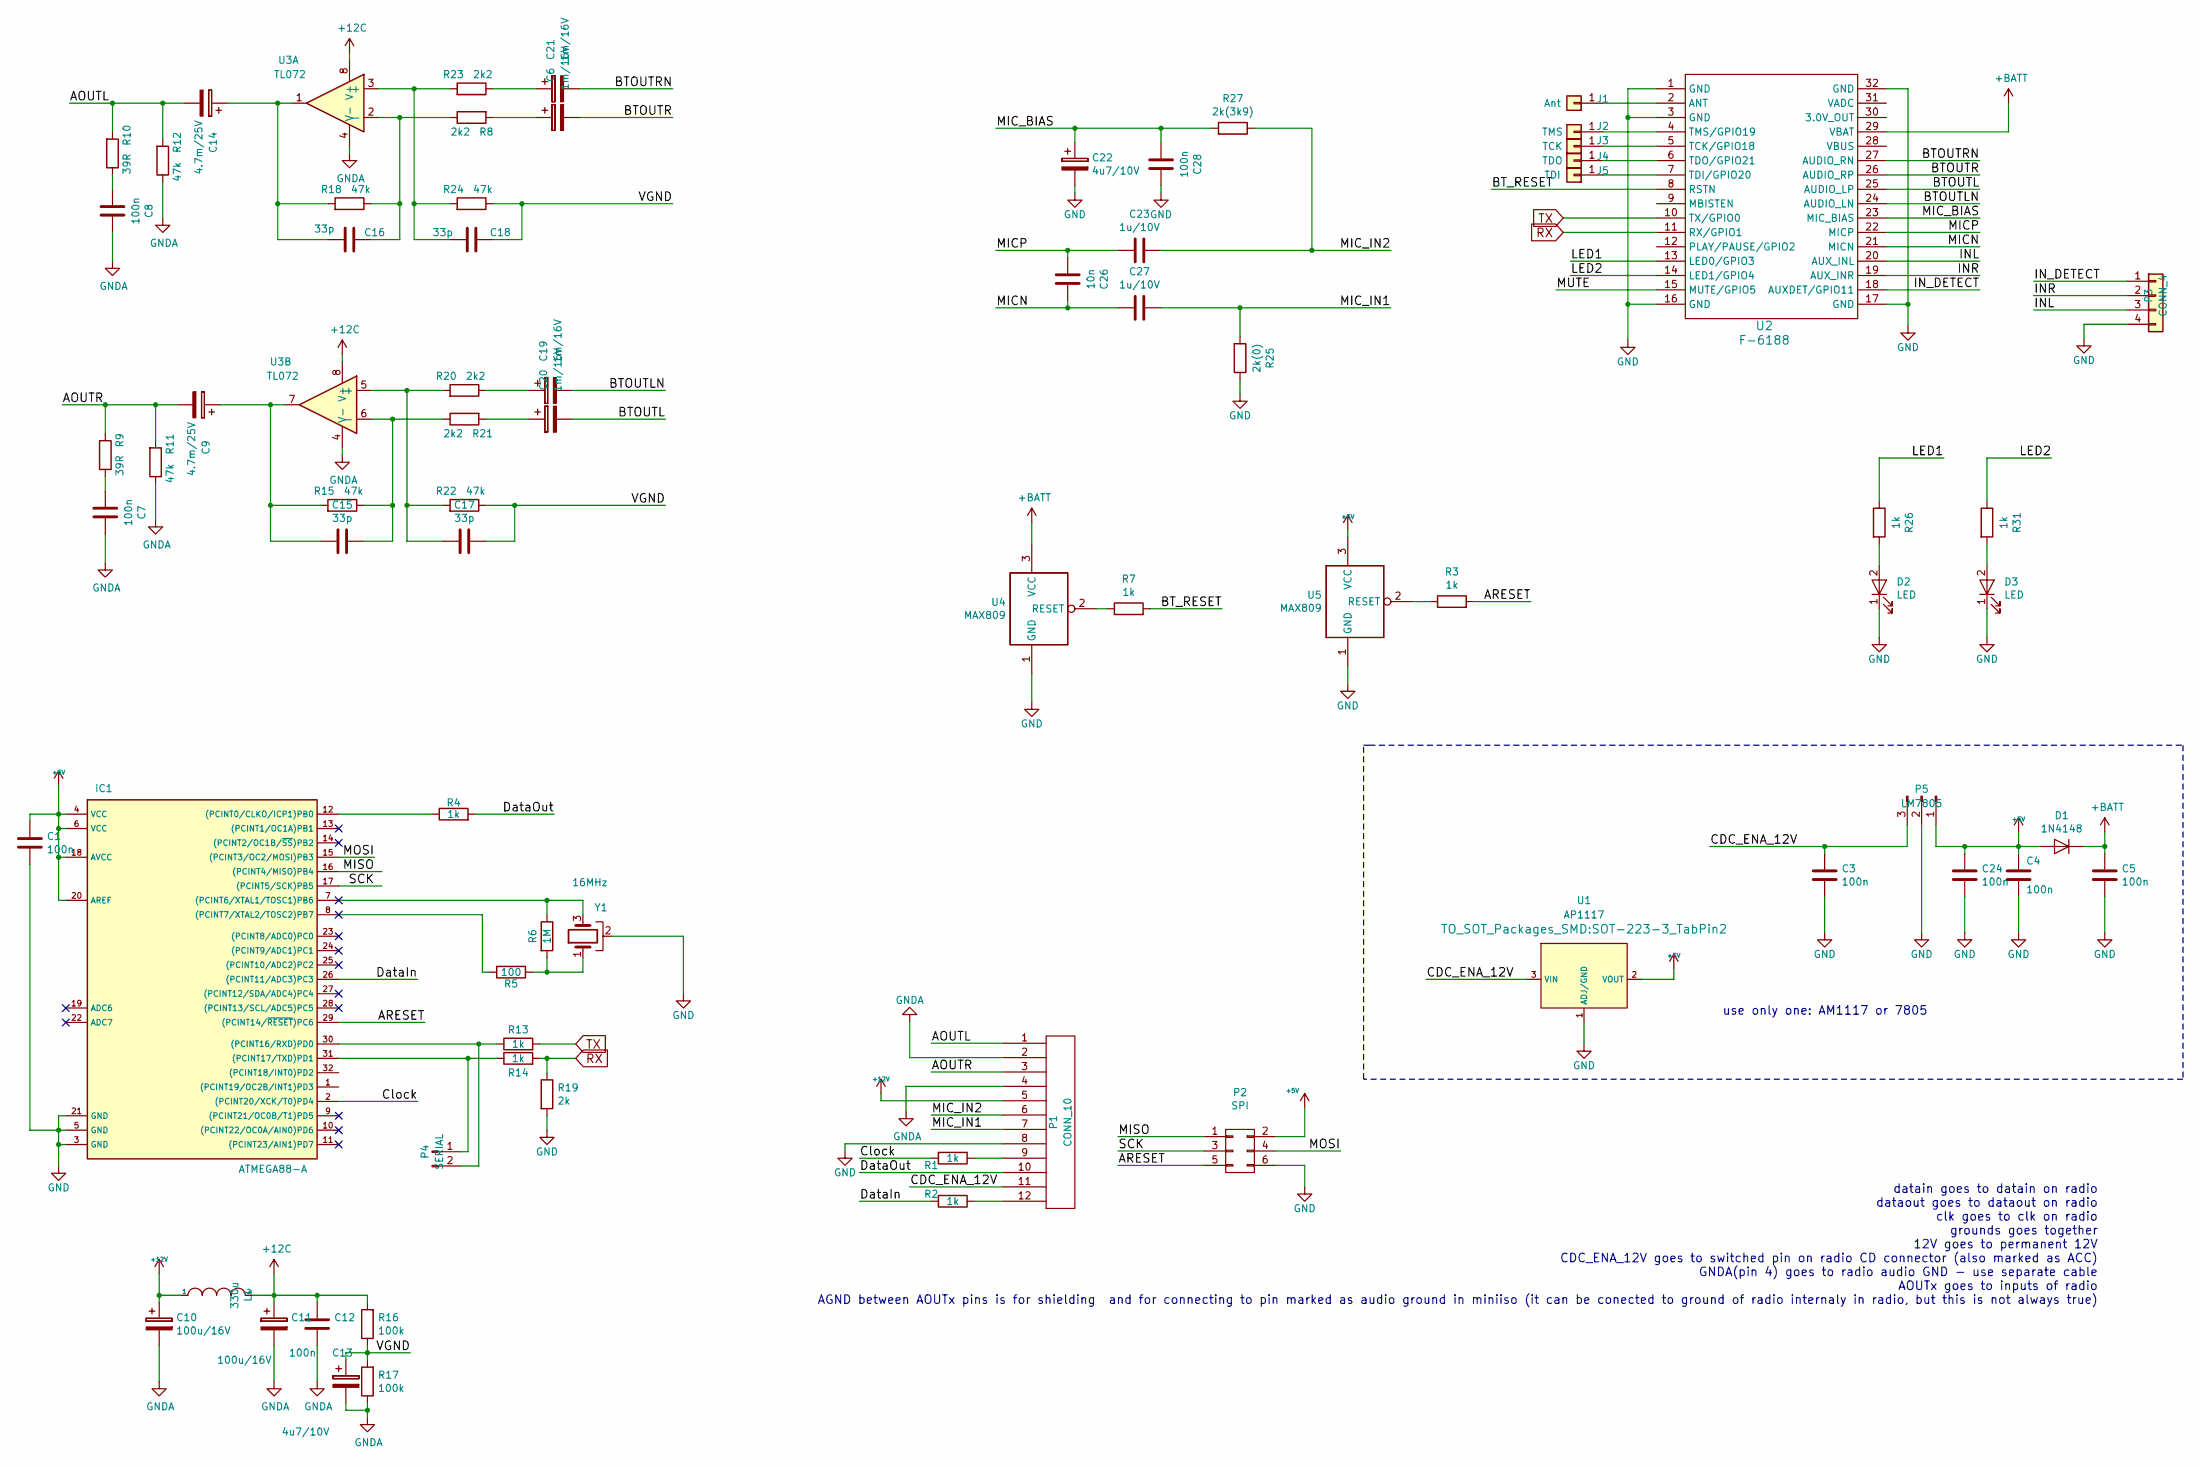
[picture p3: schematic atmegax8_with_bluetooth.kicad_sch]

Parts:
C1, C3, C4, C5, C7, C8, C12, C24, C28: 100n; C_0805_HandSoldering
C6, C19, C20, C21: 1m/16V; CP_Elec_5x5.8
C9, C14: 4.7m/25V; c_elec_6.3x5.7
C10, C11: 100u/16V; CP_Tantalum_Case-D_EIA-7343-31_Hand
C13, C22: 4u7/10V; TantalC_SizeA_EIA-3216_Wave
C15, C16, C17, C18: 33p; C_0805_HandSoldering
C23, C27: 1u/10V; C_1206_HandSoldering
C26: 10n; C_0805_HandSoldering
D1: 1N4148; D_MiniMELF
D2, D3: LED; LED_0805_HandSoldering
IC1: ATMEGA88-A; TQFP-32_7x7mm_Pitch0.8mm
J1: Ant; 1pin_smd
J2: TMS; 1pin_smd
J3: TCK; 1pin_smd
J4: TDO; 1pin_smd
J5: TDI; 1pin_smd
L1: 330u; SMD-1210_Pol
P1: CONN_10; Pin_Header_Straight_1x12_Pitch2.54mm
P2: SPI; Pin_Header_Straight_2x03
P3: CONN_4; Pin_Header_Straight_1x04
P4: SERIAL; Pin_Header_Straight_1x02_Pitch2.54mm
P5: LM7805; Pin_Header_Straight_1x03
R1, R2, R3, R4, R7, R13, R14, R26, R31: 1k; R_0805_HandSoldering
R5: 100; R_0805_HandSoldering
R6: 1M; R_0805_HandSoldering
R8, R20, R21, R23: 2k2; R_0805_HandSoldering
R9, R10: 39R; R_0805_HandSoldering
R11, R12, R15, R18, R22, R24: 47k; R_0805_HandSoldering
R16, R17: 100k; R_0805_HandSoldering
R19: 2k; R_0805_HandSoldering
R25: 2k(0); R_0805_HandSoldering
R27: 2k(3k9); R_0805_HandSoldering
U1: AP1117; SOT-223-3_TabPin2
U2: F-6188; F-6188_nosilk
U3: TL072; SOIC-8-N
U4, U5: MAX809; SOT-23
Y1: 16MHz; MURATA_CSTCE_V53

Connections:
+5V: C1.1, C4.1, C24.1, D1.2 (A), IC1.4 (VCC), IC1.6 (VCC), IC1.18 (AVCC), IC1.20 (AREF), P2.2, P5.1, U1.2 (VOUT), U5.3 (VCC)
+12C: C11.1, C12.1, L1.2, R16.2, U3.8 (V+)
+12V: C10.1, L1.1, P1.5
+BATT: C5.1, D1.1 (K), U2.29 (VBAT), U4.3 (VCC)
/AOUTL: C14.2, P1.1, R10.2, R12.2
/AOUTR: C9.2, P1.3, R9.2, R11.2
/ARESET: IC1.29 ((PCINT14/~RESET~)PC6), P2.5, R3.2
/BTOUTL: C20.2, U2.25 (AUDIO_LP)
/BTOUTLN: C19.2, U2.24 (AUDIO_LN)
/BTOUTR: C6.2, U2.26 (AUDIO_RP)
/BTOUTRN: C21.2, U2.27 (AUDIO_RN)
/BT_RESET: R7.2, U2.8 (RSTN)
/CDC_ENA_12V: C3.1, P1.11, P5.3, U1.3 (VIN)
/Clock: IC1.2 ((PCINT20/XCK/T0)PD4), R1.2
/DataIn: IC1.26 ((PCINT11/ADC3)PC3), R2.2
/DataOut: P1.10, R4.2
/INL: P3.3, U2.20 (AUX_INL)
/INR: P3.2, U2.19 (AUX_INR)
/IN_DETECT: P3.1, U2.18 (AUXDET/GPIO11)
/LED1: R26.1, U2.13 (LED0/GPIO3)
/LED2: R31.1, U2.14 (LED1/GPIO4)
/MICN: C26.2, C27.1, U2.21 (MICN)
/MICP: C23.1, C26.1, U2.22 (MICP)
/MIC_BIAS: C22.1, C28.1, R27.2, U2.23 (MIC_BIAS)
/MIC_IN1: C27.2, P1.7, R25.2
/MIC_IN2: C23.2, P1.6, R27.1
/MISO: IC1.16 ((PCINT4/MISO)PB4), P2.1
/MOSI: IC1.15 ((PCINT3/OC2/MOSI)PB3), P2.4
/SCK: IC1.17 ((PCINT5/SCK)PB5), P2.3
/VGND: C13.1, C17.2, C18.2, R16.1, R17.2, R22.1, R24.1
GND: C1.2, C3.2, C4.2, C5.2, C22.2, C24.2, C28.2, D2.1 (K), D3.1 (K), IC1.3 (GND), IC1.5 (GND), IC1.21 (GND), P1.8, P2.6, P3.4, P5.2, R19.2, R25.1, U1.1 (ADJ/GND), U2.1 (GND), U2.3 (GND), U2.16 (GND), U2.17 (GND), U2.32 (GND), U4.1 (GND), U5.1 (GND), Y1.2
GNDA: C7.2, C8.2, C10.2, C11.2, C12.2, C13.2, P1.2, P1.4, R11.1, R12.1, R17.1, U3.4 (V-)
unnamed: C6.1, R8.2
unnamed: C7.1, R9.1
unnamed: C8.1, R10.1
unnamed: C14.1, C16.1, R18.2, U3.1
unnamed: C9.1, C15.1, R15.2, U3.7
unnamed: C15.2, R15.1, R21.1, U3.6 (-)
unnamed: C16.2, R8.1, R18.1, U3.2 (-)
unnamed: C17.1, R20.2, R22.2, U3.5 (+)
unnamed: C18.1, R23.2, R24.2, U3.3 (+)
unnamed: C19.1, R20.1
unnamed: C20.1, R21.2
unnamed: C21.1, R23.1
unnamed: D2.2 (A), R26.2
unnamed: D3.2 (A), R31.2
unnamed: IC1.7 ((PCINT6/XTAL1/TOSC1)PB6), R6.1, Y1.3
unnamed: IC1.8 ((PCINT7/XTAL2/TOSC2)PB7), R5.2
unnamed: IC1.12 ((PCINT0/CLKO/ICP1)PB0), R4.1
unnamed: IC1.30 ((PCINT16/RXD)PD0), P4.2, R13.1
unnamed: IC1.31 ((PCINT17/TXD)PD1), P4.1, R14.1
unnamed: J1.1, U2.2 (ANT)
unnamed: J2.1, U2.4 (TMS/GPIO19)
unnamed: J3.1, U2.5 (TCK/GPIO18)
unnamed: J4.1, U2.6 (TDO/GPIO21)
unnamed: J5.1, U2.7 (TDI/GPIO20)
unnamed: P1.9, R1.1
unnamed: P1.12, R2.1
unnamed: R3.1, U5.2 (RESET)
unnamed: R5.1, R6.2, Y1.1
unnamed: R7.1, U4.2 (RESET)
RX: R14.2, R19.1, U2.11 (RX/GPIO1)
TX: R13.2, U2.10 (TX/GPIO0)

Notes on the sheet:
use only one: AM1117 or 7805
datain goes to datain on radio dataout goes to dataout on radio clk goes to clk on radio grounds goes together 12V goes to permanent 12V CDC_ENA_12V goes to switched pin on radio CD connector (also marked as ACC) GNDA(pin 4) goes to radio audio GND - use separate cable AOUTx goes to inputs of radio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

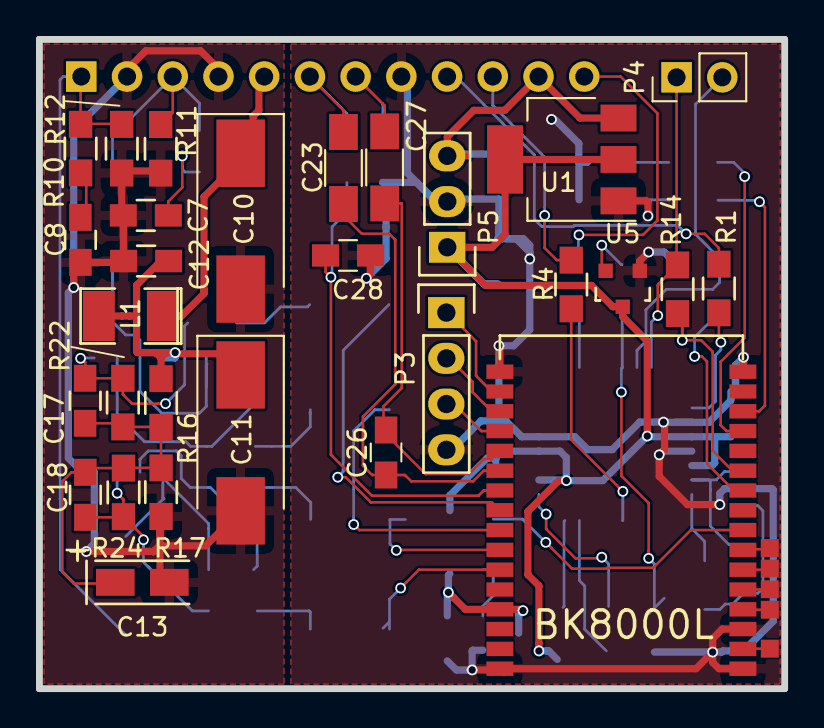
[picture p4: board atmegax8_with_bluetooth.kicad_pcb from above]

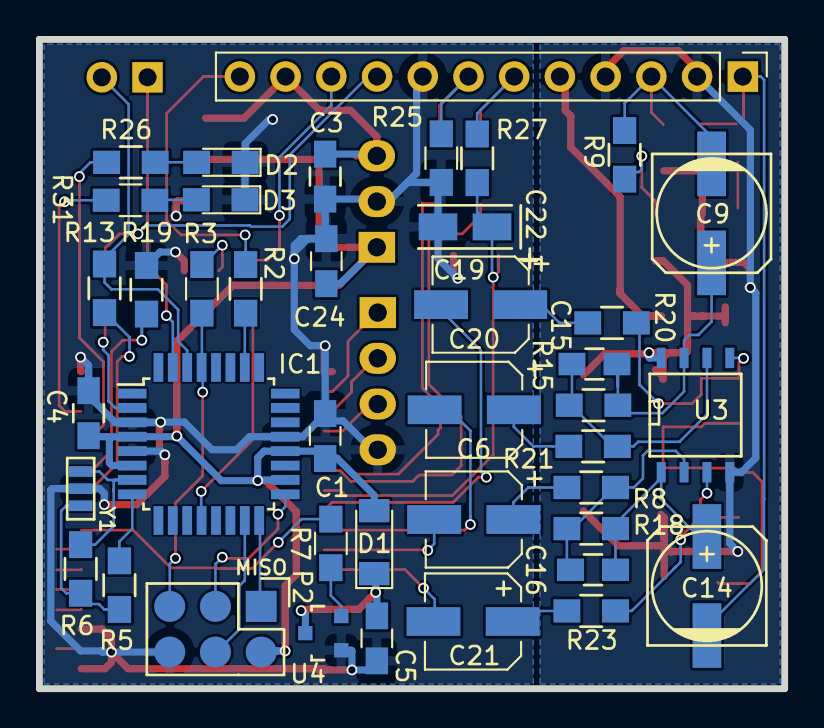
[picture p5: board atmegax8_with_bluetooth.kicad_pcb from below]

Board: 2 copper layers, 41.4 x 36.1 mm, 75 parts (41 on the bottom side), 63 nets.

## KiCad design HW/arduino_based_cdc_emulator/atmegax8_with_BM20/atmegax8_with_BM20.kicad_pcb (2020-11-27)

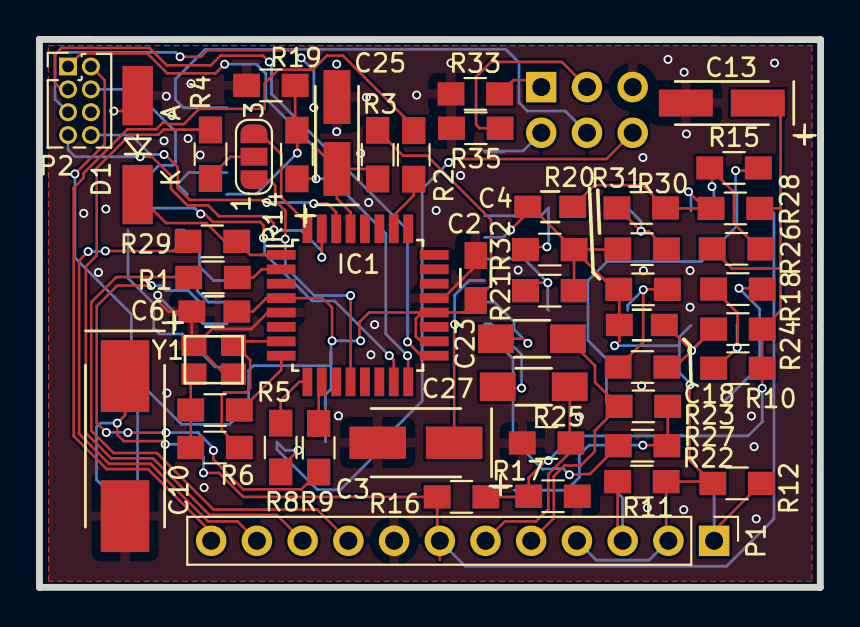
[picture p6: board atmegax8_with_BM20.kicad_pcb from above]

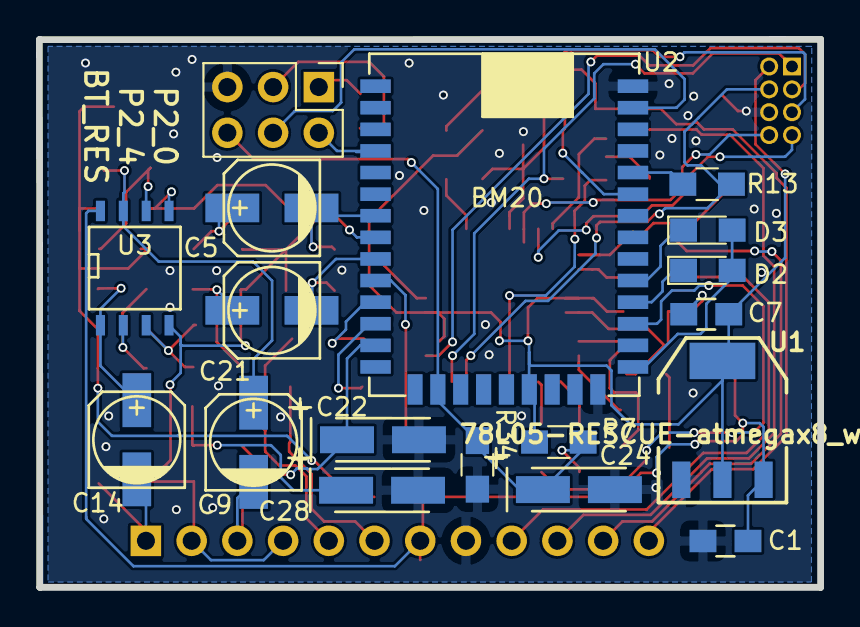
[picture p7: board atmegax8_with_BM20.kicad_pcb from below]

Board: 2 copper layers, 43.4 x 30.4 mm, 66 parts (18 on the bottom side), 56 nets.

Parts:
C1, C2, C6, C7: 100n; C_0805_HandSoldering
C3: 10m/16V; TantalC_SizeB_EIA-3528_HandSoldering
C4, C18: NP; C_0805_HandSoldering
C5, C21: 4m7/16V; c_elec_5x5.8
C9: 10m/16V; c_elec_5x5.8
C10: CTS 47u/25V D 10% VIS-293D; TantalC_SizeD_EIA-7343_HandSoldering
C13: 2m2/16V; TantalC_SizeA_EIA-3216_HandSoldering
C14: 10u/16V; c_elec_5x5.8
C22, C28: 2u2/16V; TantalC_SizeA_EIA-3216_HandSoldering
C23, C27: 1u/10V; C_1206_HandSoldering
C24, C25: 2u2; TantalC_SizeA_EIA-3216_HandSoldering
D1: 5V1; MiniMELF_Handsoldering
D2, D3: LED; LED_0805_HandSoldering
IC1: ATMEGA328PB-AU; TQFP-32_7x7mm_Pitch0.8mm
J1: TEST_FLASH_MODE; Pin_Header_Straight_2x03_Pitch2.54mm
JP1: Jumper_3_Bridged12; SolderJumper-3_P1.3mm_Open_RoundedPad1.0x1.5mm_NumberLabels
P1: CONN_10; Pin_Header_Straight_1x12_Pitch2.54mm
P2: SPI; Pin_Header_Straight_2x04_Pitch1.27mm
R1, R2, R3, R4, R7: 3k3; R_0805_HandSoldering
R5: 27; R_0805_HandSoldering
R6: 1M; R_0805_HandSoldering
R8, R9, R13, R14: 330; R_0805_HandSoldering
R10, R11, R12, R16, R17, R24, R26, R28: 100k; R_0805_HandSoldering
R15, R18: 2M2; R_0805_HandSoldering
R19, R33, R34, R35: 4k7; R_0805_HandSoldering
R20, R21, R31, R32: NP; R_0805_HandSoldering
R22, R27: 1k; R_0805_HandSoldering
R23, R30: 0; R_0805_HandSoldering
R25: 2k; R_0805_HandSoldering
R29: 10k; R_0805_HandSoldering
U1: 78L05-RESCUE-atmegax8_with_BM20; SOT-223-REGULATOR
U2: BM20
U3: LM358; SOIC-8-N
Y1: Crystal_GND24; crystal_FA238-TSX3225

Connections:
+5V: C2.1, C6.1, C7.1, IC1.4 (VCC), IC1.18 (AVCC), IC1.20 (AREF), P2.2, R3.2, R7.2, U1.VO, U2.20 (ADAP_IN)
+12V: C1.1, C10.1, P1.7, R16.2, U1.VI, U3.8 (V+)
/AOUTL: C14.2, P1.1, R12.2
/AOUTR: C9.2, P1.3, R11.2
/ARESET: C25.1, IC1.29 ((~RESET~)PC6), P2.5, R3.1
/BTOUTL: C21.2, R21.2, U2.9 (SPKL)
/BTOUTR: C5.2, R32.2, U2.7 (SPKR)
/BT_RESET: C24.1, J1.6, R7.1, R8.2, R34.1, U2.16 (RST)
/BT_RX: R13.2, U2.33 (HCI_RXD)
/BT_TX: R14.2, R19.1, U2.32 (HCI_TXD)
/CDC_ENA_5V: D1.1 (K), IC1.1 ((OC2B/INT1/PTCXY)PD3), R29.1
/CDC_ENA_12V: P1.11, R29.2
/Clock: IC1.2 ((XCK0/T0/PTCXY)PD4), R1.2
/DataIn: IC1.26 ((ADC3/PTCY)PC3), R2.2
/DataOut: P1.10, R4.2
/LED1: D2.1 (K), U2.27 (LED1)
/LED2: D3.1 (K), U2.28 (LED2)
/MFB: R9.2, U2.26 (MFB)
/MICN: C27.1, U2.12 (MIC1_N)
/MICP: C23.1, U2.11 (MIC1_P)
/MIC_BIAS: C22.1, R22.2, U2.13 (MIC_BIAS)
/MIC_IN1: C27.2, P1.6, R25.2
/MIC_IN2: C23.2, P1.5, R27.1
/MISO: IC1.16 ((MISO0/RXD1/PTCXY)PB4), P2.1, R14.1
/MOSI: IC1.15 ((MOSI0/TXD1/OC2A/PTCXY)PB3), P2.4, R13.1
/P2_0: J1.2, U2.4 (P2_0)
/P2_4: J1.4, U2.36 (P2_4)
/RX: IC1.30 ((RXD0/OC3A/PTCXY)PD0), P2.8
/SCK: IC1.17 ((XCK0/SCK0/PTCXY)PB5), P2.3
/SYSPWR: D2.2 (A), D3.2 (A), U2.24 (SYS_PWR)
/TX: IC1.31 ((TXD0/OC4A/PTCXY)PD1), P2.7
/VGND: C13.1, R10.1, R16.1, R17.2, R24.1, R26.1, R28.1
GND: C1.2, C2.2, C3.2, C6.2, C7.2, C10.2, C13.2, C22.2, C24.2, C25.2, C28.2, D1.2 (A), IC1.5 (GND), IC1.21 (GND), J1.5, P1.8, P2.6, R17.1, R19.2, R25.1, R33.1, R34.2, R35.2, U1.GND, U2.23 (GND), U2.37 (GND), Y1.3
GNDA: C4.2, C18.2, P1.2, P1.4, R11.1, R12.1, R20.1, R21.1, R31.1, R32.1, U2.8 (AOHPM), U3.4 (V-)
unnamed: C3.1, U2.10 (VDDA)
unnamed: C4.1, R28.2, R30.2, U3.5 (+)
unnamed: C5.1, R30.1, R31.2
unnamed: C9.1, R15.2, U3.7
unnamed: C14.1, R18.2, U3.1
unnamed: C18.1, R23.2, R24.2, U3.3 (+)
unnamed: C21.1, R20.2, R23.1
unnamed: C28.1, R22.1, R27.2
unnamed: IC1.7 ((XTAL1/TOSC1)PB6), R6.1, Y1.2
unnamed: IC1.8 ((XTAL2/TOSC2)PB7), R5.2
unnamed: IC1.9 ((OC0B/T1/PTCXY)PD5), R8.1
unnamed: IC1.10 ((OC0A/AIN0/PTCXY)PD6), R9.1
unnamed: IC1.12 ((CLKO/ICP1/PTCXY)PB0), JP1.1 (A)
unnamed: IC1.32 ((OC3B/OC4B/INT0/PTCXY)PD2), JP1.3 (B)
unnamed: J1.1, R33.2
unnamed: J1.3, R35.1
unnamed: JP1.2 (C), R4.1
unnamed: P1.9, R1.1
unnamed: P1.12, R2.1
unnamed: R5.1, R6.2, Y1.1
unnamed: R10.2, R18.1, U3.2 (-)
unnamed: R15.1, R26.2, U3.6 (-)

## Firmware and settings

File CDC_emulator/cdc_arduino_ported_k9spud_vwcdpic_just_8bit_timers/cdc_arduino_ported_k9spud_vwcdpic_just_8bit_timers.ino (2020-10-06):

/*****************************************************************************
   Audi/Volkswagen Audi Interface
   Target: arduino atmega328(tested)
           attinu85 (tested)
   Author: Vincent
   Date: January, 2011
   Version: 0.01

   Originally ported from VWCDPIC Project:
   http://www.k9spud.com/vwcdpic/

   Ported from Matthias Koelling's AVR Code:
   www.mikrocontroller.net/attachment/31279/vwcdc.c

   ---------------------------------
   16. Mar 2015:

   https://github.com/tomaskovacik/
   arduino duemilanove works:

   UNO,Duemilanove,nanoe ... atmegax8 base boards:
   RADIO PIN -> arduino pin

   DataOut   -> digital 2 (INT0)
   DataIn    -> digital 11(PB3)
   Clock     -> digital 13(PB5)

   PC PIN    -> arduino pin
   Serial TX -> digital 0 (PD0)
   Serial RX -> digital 1 (PD1)

   ANDROID support:
   PREVIOUS BUTTON -> digital 7 (PD7)
   PLAY BUTTON -> digital 6 (PD6)
   NEXT BUTTON -> digital 5 (PD5)

   to enable android remote control over headphone buttons emulation uncoment #define ANDROID_HEADPHONES
   for one button control (SONY) uncoment #define ANDROID_HEADPHONES_ONE_BUTTON

   android headphone support, pinout:
   play button control:arduino pin 5 (chip pin 11)
   previous button control: arduino pin 9 (chip pin 15)
   next button control: arduino pin 6 (chip pin 12)

   6. Aug 2015  tomaskovacik
    - 2 8-bit timers used
    - INT0 is used
    - attiny85 pinout
    - merge with attiny85 port

   8. Oct 2015 tomas
    - init support for arduino 3-button remote control over headphone mic line
    - init support for sony single buttone remote control on headphone mic line


   ATTINYx5 version:

   RADIO PIN -> ATTINYx5 PIN
   DataOut   -> 7 (INT0)
   Clock     -> 6 (PB1)
   DataIn    -> 5 (PB0)

   PC PIN    -> ATTINYx5 PIN
   Serial TX -> 2 (PB3) using tinydebug lib
   Serial RX -> not connected

   what you need  to install:
   ATTinycore: https://github.com/SpenceKonde/ATTinyCore (supported directly in arduino(from version 1.6.3) via board manager )
   TinyDebugSerial from: https://github.com/jscrane/TinyDebugSerial (download and extract into libraries Arduino folder)

   select attiny25/45/85 board from tools-> board -> (ATTinyCore) ATtiny25/45/85
   select attiny85 from tools->chip->ATtiny85
   select internal 8Mhz from tools->Clock -> 8MHz (internal)

   to use digispark uncoment line //#define DIGISPARK
   then use 16MHz-noUSB settings
   tested with ATTinyCore with Digispark support: https://github.com/tomaskovacik/ATTinyCore/
   maybe will be merged in oficial ATTinyCore in the future

   kovo 1.jul 2019
   - atmega324 using INT2 /on pins INT0 and INT1 is 2nd uart

   kovo 3.ju l2019
    - attiny167 using ICP1/digi10 for command and 0 and 1 for data/clk pins

 *****************************************************************************/
//#define DIGISPARK

#ifdef DIGISPARK
#include <avr/power.h>
#endif

#if defined(__AVR_ATmega8__) || defined(__AVR_ATmega128__)
#define TCCR2A TCCR2
#define TCCR2B TCCR2
#define COM2A1 COM21
#define COM2A0 COM20
#define OCR2A OCR2
#define TIMSK2 TIMSK
#define OCIE2A OCIE2
#define TIMER2_COMPA_vect TIMER2_COMP_vect
#define TIMSK1 TIMSK
#define TIFR1 TIFR
#define ICIE1 TICIE1
#define TIMSK0 TIMSK
#define TIFR0 TIFR
#define OCF2A OCF2
#define TCCR0A TCCR0
#define TCCR0B TCCR0
#define EIMSK GICR
#define OCIE0A OCIE0
#define EICRA MCUCR
#define EIFR GIFR
#endif

// uncoment this to have original fSerial outputs for PJRC players
//#define PJRC

/* enable hex control command on Serial line to control mpd control
   script with shyd.de control script
*/
//#define JUST_HEX_TO_SERIAL

/* enable bluetooth module control over Serial line
   XS3868
*/
//#define BLUETOOTH
#ifdef BLUETOOTH
#define SERIAL_BAUDRATE 9600
#else
#define SERIAL_BAUDRATE 9600
#endif
/*
   read disc# track# status over serial line
*/
//#define DISC_TRACK_NUMBER_FROM_MPD

/*
   ANDROID HEADPRONES SUPPORT
   HTC: 3buttons, 220ohm previous|0ohm play/pause|470ohm next
*/
//#define ANDROID_HEADPHONES

/*
   ANDROID HEADPHONES SUPORT
   SONY: 1button mode: 1xpush play/pause;2xpush previous;3xpush next
*/
//#define ANDROID_HEADPHONES_ONE_BUTTON

#ifdef ANDROID_HEADPHONES_ONE_BUTTON //just to be shure
#define ANDROID_HEADPHONES
#endif


#if defined(__AVR_ATtiny85__)
//https://github.com/jscrane/TinyDebugSerial
//#ifdef DIGISPARK
//no softwarserial in digispark ...
#include <TinyDebugSerial.h>
TinyDebugSerial mySerial = TinyDebugSerial();
//#else
//#include <SoftwareSerial.h>
//SoftwareSerial mySerial(NULL, PB3);
//#endif
//tiny has only Rx, so by default we disable all features which use TX
#undef DISC_TRACK_NUMBER_FROM_MPD
#undef ANDROID_HEADPHONES
#undef ANDROID_HEADPHONES_ONE_BUTTON
#define Serial mySerial
#else
#include <HardwareSerial.h>
#endif

#define TRUE 1

// Low period of PWTX line:
// 0: ~650us
// 1: ~1.77ms
// S: ~4.57ms

// one tick is 0.5µs
#define STARTTHRESHOLD  6400            // greater than this signifies START bit
#define HIGHTHRESHOLD   2496       // greater than this signifies 1 bit.
#define LOWTHRESHOLD    512        // greater than this signifies 0 bit.
#define PKTSIZE          -32            // command packets are 32 bits long.

// do not refresh head unit faster than 5.5ms (currently not implemented)
// 5.24s slow refresh rate when head unit in FM/AM/Tape mode (not implemented)

//#define REFRESH_PERIOD   50        // default to refresh head unit every 50.0ms
#define SECONDWAIT      -20         // wait 20 * 50ms to get 1 second (50ms*20 = 1000ms = 1s)
#define POWERIDENTWAIT  -10         // wait 10 * 1s to 10 seconds between VWCDPICx.x display
#define SCANWAIT        -100        // wait 100 * 50ms to get 5sec (50ms*100 = 5000ms = 5s)
#define _50MS            5000
#define _700US            70
#define _10US            1
#define CLK_DELAY 5
#define TX_BUFFER_END   12
#define CAP_BUFFER_END	24

//android headphones
#ifdef ANDROID_HEADPHONES
#define ANDROID_PUSH_COUNT 2 //100ms push - how long push take 
#define ANDROID_DELAY_COUNT 1 //50ms delay - how long we wait between pushes
#endif
#ifdef ANDROID_HEADPHONES_ONE_BUTTON
#define ANDROID_PLAY_COUNT 1 //how much pushes need to make it play
#define ANDROID_NEXT_COUNT 2 //how much pushes need to make it next
#define ANDROID_PREV_COUNT 3 //how much pushes need to make it previous
#endif

#define VER_MAJOR       '1'
#define VER_MINOR       '1'
#define VER_PATCHLEVEL  'd'

#if defined(__AVR_ATtiny85__) || defined(__AVR_ATtiny45__)
#define RADIO_COMMAND      PB2
#define RADIO_COMMAND_DDR  DDRB
#define RADIO_COMMAND_PORT PORTB
#define RADIO_COMMAND_PIN PINB
#define RADIO_CLOCK        PB1
#define RADIO_CLOCK_DDR    DDRB
#define RADIO_CLOCK_PORT    PORTB
#define RADIO_DATA         PB0
#define RADIO_DATA_DDR     DDRB
#define RADIO_DATA_PORT    PORTB

#elif defined(__AVR_ATmega328__) || defined(__AVR_ATmega328A__) || defined(__AVR_ATmega328P__) || defined(__AVR_ATmega328PA__) || defined(__AVR_ATmega328PB__) || \
      defined(__AVR_ATmega168__) || defined(__AVR_ATmega168A__) || defined(__AVR_ATmega168P__) || defined(__AVR_ATmega168PA__) || defined(__AVR_ATmega168PB__) || \
       defined(__AVR_ATmega88__) ||  defined(__AVR_ATmega88A__) ||  defined(__AVR_ATmega88P__) ||  defined(__AVR_ATmega88PA__) ||  defined(__AVR_ATmega88PB__)
//INT0 = PD2
#define RADIO_COMMAND      PD2
#define RADIO_COMMAND_DDR  DDRD
#define RADIO_COMMAND_PORT PORTD
#define RADIO_COMMAND_PIN PIND
#define RADIO_CLOCK        PB5
#define RADIO_CLOCK_DDR    DDRB
#define RADIO_CLOCK_PORT    PORTB
#define RADIO_DATA        PB3
#define RADIO_DATA_DDR     DDRB
#define RADIO_DATA_PORT    PORTB

#elif defined(__AVR_ATmega324__) || defined(__AVR_ATmega324P__) || defined(__AVR_ATmega324A__) || defined(__AVR_ATmega324PA__) || defined(__AVR_ATmega324PB__)
//INT2 = PD6
#define RADIO_COMMAND      PB2 //PD
#define RADIO_COMMAND_DDR  DDRB
#define RADIO_COMMAND_PORT PORTB
#define RADIO_COMMAND_PIN PINB
#define RADIO_CLOCK        PB7
#define RADIO_CLOCK_DDb    DDB7
#define RADIO_CLOCK_DDR    DDRB
#define RADIO_CLOCK_PORT  PORTB
#define RADIO_DATA         PB5
#define RADIO_DATA_DDb     DDB5
#define RADIO_DATA_DDR     DDRB
#define RADIO_DATA_PORT  PORTB

#elif defined(__AVR_ATtiny167__)
//ICP1 = PA4
#define RADIO_COMMAND      PA4 //ICP1 10
#define RADIO_COMMAND_DDR  DDRA
#define RADIO_COMMAND_PORT PORTA
#define RADIO_COMMAND_PIN PINA
#define RADIO_CLOCK        PB1 //1
#define RADIO_CLOCK_DDb    DDB1
#define RADIO_CLOCK_DDR    DDRB
#define RADIO_CLOCK_PORT  PORTB
#define RADIO_DATA         PB0 //0
#define RADIO_DATA_DDb     DDB0
#define RADIO_DATA_DDR     DDRB
#define RADIO_DATA_PORT  PORTB

#endif

#ifdef ANDROID_HEADPHONES
#define ANDROID_NEXT       PD5 //android next button control arduino pin 5 (chip pin 11)
#define ANDROID_NEXT_DDR   DDRD
#define ANDROID_NEXT_PORT    PORTD
#define ANDROID_PLAY       PD6 //android play button control arduino pin 6 (chip pin 12)
#define ANDROID_PLAY_DDR   DDRD
#define ANDROID_PLAY_PORT    PORTD
#define ANDROID_PREV       PD7 //android previous button control arduino pin 7 (chip pin 13)
#define ANDROID_PREV_DDR   DDRD
#define ANDROID_PREV_PORT    PORTD
#endif

// Command Codes
// -------------
//
// First byte is always 53
// Second byte is always 2C
// Third and Fourth bytes always add up to FF
// All command codes seem to be a multiple of 4.
//
//
// 53 2C 0C F3 CD 1
// 53 2C 10 EF DISABLE
// 53 2C 14 EB Change CD (ignored)
// 53 2C 18 E7 Previous CD (only on Audi Concert <)
// 53 2C 2C D3 CD 5 (first packet)
// 53 2C 38 C7 Change CD/Next CD (aka MINQUIRY)
// 53 2C 4C B3 CD 3 (first packet)
// 53 2C 58 A7 Seek Back Pressed
// 53 2C 60 9F Mix 1
// 53 2C 68 97 Up on Mk3 premium (Adam Yellen)
// 53 2C 78 87 Dn
// 53 2C 8C 73 CD 2 (first packet)
// 53 2C A0 5F Scan
// 53 2C A4 5B something to do with power on (Audi Concert)
// 53 2C A8 57 Dn on Mk3 premium (Adam Yellen <adam@yellen.com>)
// 53 2C AC 53 CD 6 (first packet)
// 53 2C CC 33 CD 4 (first packet)
// 53 2C D8 27 Seek Forward Pressed
// 53 2C E0 1F Mix 6
// 53 2C E4 1B ENABLE
// 53 2C F8 07 Up


//#define  Do_PLAY           0x08  // mix button held down (RCD300 head unit only)
#define  Do_PLAY           0x03  // mix button held down (RCD300 head unit only)
#define  Do_LOADCD			0x01	// not used
#define  Do_ENABLE_MK      0x08  // mk concert1
#define  Do_CD1            0x0C  // CD 1
#define  Do_DISABLE        0x10  // DISABLE
#define  Do_CHANGECD       0x14  // Change CD (changer ignores & no ACK)
#define  Do_PREVCD         0x18  // PREVIOUS CD (Audi Concert head unit)
#define  Do_CD5            0x2C  // CD 5
#define  Do_TP             0x30  // TP info (TP button pressed)
#define  Do_SEEKFORWARD_MK 0x38  // mk concert 1 LOAD CD (aka MINQUIRY).
// Also means "Next CD" if no CD button pressed
#define  Do_CD3            0x4C  // CD 3
#define  Do_SEEKBACK       0x58  // SEEK BACK
#define  Do_MIX_CD         0x60  // MIX 1 (mix tracks within one disc)
#define  Do_UP_MK3         0x68  // UP (Mk3 head unit)
#define  Do_DOWN           0x78  // DOWN
#define  Do_CD2            0x8C  // CD 2
#define  Do_SCAN           0xA0  // SCAN
#define  Do_UNKNOWNCMD     0xA4  // power on CD mode?? (Audi Concert head unit)
#define  Do_DOWN_MK3       0xA8  // DOWN (Mk3 head unit only)
#define  Do_CD6            0xAC  // CD 6
#define  Do_CD4            0xCC  // CD 4
#define  Do_SEEKFORWARD    0xD8  // Seek Forward
#define  Do_MIX            0xE0  // MIX 6 (mix tracks across all discs)
#define  Do_ENABLE         0xE4  // ENABLE
#define  Do_UP             0xF8  // UP
//#define DUMPMODE
//#define DUMPMODE2

enum STATES
{
  StateIdle,
  StateIdleThenPlay,
  StateInitPlay,
  StateInitPlayEnd,
  StateInitPlayAnnounceCD,
  StatePlayLeadIn,
  StatePlayLeadInEnd,
  StatePlayLeadInAnnounceCD,
  StateTrackLeadIn,
  StatePlay,
  StateTP
};

/* -- Types ---------------------------------------------------------------- */
/* -- Extern Global Variables ---------------------------------------------- */

#ifdef BLUETOOTH
const uint8_t sDATAERR[] PROGMEM = "\r\n";
const uint8_t sOVERFLOW[] PROGMEM = "\r\n";
const uint8_t sMDISABLE[] PROGMEM = "AT#MA\r\n";
const uint8_t sMENABLE[] PROGMEM = "AT#MA\r\n";
const uint8_t sMINQUIRY[] PROGMEM = "MINQUIRY\r\n";
const uint8_t sPRV_LIST[] PROGMEM = "AT#MA\r\n";
const uint8_t sNXT_LIST[] PROGMEM = "AT#MA\r\n";
const uint8_t sLIST1[] PROGMEM = "AT#MA\r\n";
const uint8_t sLIST2[] PROGMEM = "AT#MA\r\n";
const uint8_t sLIST3[] PROGMEM = "AT#MA\r\n";
const uint8_t sLIST4[] PROGMEM = "AT#MA\r\n";
const uint8_t sLIST5[] PROGMEM = "AT#MA\r\n";
const uint8_t sLIST6[] PROGMEM = "AT#MA\r\n";
const uint8_t sRANDOM[] PROGMEM = "RANDOM\r\n";
const uint8_t sPLAY[] PROGMEM = "AT#MA\r\n";
const uint8_t sSCAN[] PROGMEM = "SCAN\r\n";
const uint8_t sSTOP[] PROGMEM = "AT#MA\r\n";
const uint8_t sNEXT[] PROGMEM = "AT#MD\r\n";
const uint8_t sPREVIOUS[] PROGMEM = "AT#ME\r\n";
const uint8_t sRING[] PROGMEM = "\r\n";
const uint8_t sIDENTIFY[] PROGMEM = "\r\n";
const uint8_t sNEWLINE[] PROGMEM = "\r\n";
const uint8_t sDASH[] PROGMEM = "";
const uint8_t sHEX[] PROGMEM = "";
const uint8_t sVERSION[] PROGMEM = "";
#else
const uint8_t sDATAERR[] PROGMEM = "dataerr\r\n";
const uint8_t sOVERFLOW[] PROGMEM = "overflow\r\n";
const uint8_t sMDISABLE[] PROGMEM = "MDISABLE\r\n";
const uint8_t sMENABLE[] PROGMEM = "MENABLE\r\n";
const uint8_t sMINQUIRY[] PROGMEM = "MINQUIRY\r\n";
const uint8_t sPRV_LIST[] PROGMEM = "PRV_LIST\r\n";
const uint8_t sNXT_LIST[] PROGMEM = "NXT_LIST\r\n";
const uint8_t sLIST1[] PROGMEM = "LIST1\r\n";
const uint8_t sLIST2[] PROGMEM = "LIST2\r\n";
const uint8_t sLIST3[] PROGMEM = "LIST3\r\n";
const uint8_t sLIST4[] PROGMEM = "LIST4\r\n";
const uint8_t sLIST5[] PROGMEM = "LIST5\r\n";
const uint8_t sLIST6[] PROGMEM = "LIST6\r\n";
const uint8_t sRANDOM[] PROGMEM = "RANDOM\r\n";
const uint8_t sPLAY[] PROGMEM = "PLAY\r\n";
const uint8_t sSCAN[] PROGMEM = "SCAN\r\n";
const uint8_t sSTOP[] PROGMEM = "STOP\r\n";
const uint8_t sNEXT[] PROGMEM = "NEXT\r\n";
const uint8_t sPREVIOUS[] PROGMEM = "PREVIOUS\r\n";
const uint8_t sRING[] PROGMEM = "RING\r\n";
const uint8_t sIDENTIFY[] PROGMEM = "Audi Concert I Multimedia Gateway Ver.";
const uint8_t sNEWLINE[] PROGMEM = "\r\n";
const uint8_t sDASH[] PROGMEM = "_";
const uint8_t sTP[] PROGMEM = "TP\r\n";
const uint8_t sHEX[] PROGMEM = {
  '0', 0, '1', 0, '2', 0, '3', 0, '4', 0, '5', 0, '6', 0, '7', 0, '8', 0, '9', 0, 'A', 0, 'B', 0, 'C', 0, 'D', 0, 'E', 0, 'F', 0
};
const uint8_t sVERSION[] PROGMEM = {
  VER_MAJOR, '.', VER_MINOR, VER_PATCHLEVEL, 0
};
#endif

uint8_t sendreg;
uint8_t sendbitcount; // Used in SendByte routine

uint8_t disc = 1;
uint8_t track = 1;
uint8_t minute = 0;
uint8_t second = 0;

uint8_t scanptr; // pointer to command byte to inspect next
uint8_t fsr;
uint8_t scanbyte; // most recently retrieved command byte
uint8_t cmdcode; // command code received from head unit (byte 3)

// these storage bytes are for the ISR to save process state so that it
// doesn't adversely affect the main loop code. you must -not- use these
// variables for anything else, as the ISR -will- corrupt them.

uint8_t intwsave;
uint8_t intstatussave;
uint8_t intfsrsave;

// the 'capbusy' flag will be set when the ISR is busy capturing a command
// packet from the head unit. The TMR0 ISR will clear it once the recieve
// timeout has been exceeded or the PWTX capture ISR will clear it once
// 32 bits have been captured (command packets are supposed to be 32 bits
// long only).

uint8_t capbusy;

// 'mix' and 'scan' flags specify whether we want to light up the MIX light
// or SCAN display on the head unit.

uint8_t mix;
uint8_t scan;
uint8_t playing;
uint8_t cd_button = 0;
uint8_t mix_button = 0;

// The ISR will set 'dataerr' flag if it detected a framing error
// or 'overflow' if it overflowed the capture buffer queue.

uint8_t overflow;
uint8_t dataerr;
uint8_t _1us_delay = 0;

#ifdef DUMPMODE
// The ISR will set 'startbit' flag if it detected a start bit.
uint8_t startbit;
#endif



uint16_t captime; // timer count of low pulse (temp)
uint16_t captime_ovf; //overflow counts of 8bit timer1
int8_t capbit; // bits left to capture for this byte
int8_t capbitpacket; // bits left to capture for the entire packet
uint8_t capptr; // pointer to packet capture buffer loc

uint8_t BIDIstate; // pointer to the current state handler routine
int8_t BIDIcount; // counts how long to stay in current state
uint8_t ACKcount; // number of ACK bits to set.
uint8_t discload; // next disc number to load

int8_t poweridentcount; // counts down until we should send VWCDPICx.x
uint8_t secondcount; // counts down until one second has passed
int8_t scancount; // used to count down displaying SCAN mode

uint8_t txinptr;
uint8_t txoutptr;
uint8_t display_byte_buffer_mau8[8]; // holds display bytes sent to the head unit
uint8_t const *txbuffer[TX_BUFFER_END]; // 39-26-1 = 12 serial output strings queue
uint8_t capbuffer[CAP_BUFFER_END]; // 64-39-1 = 24 bytes for head unit command

uint16_t counter_50ms = _50MS; // counter for 10ms intervals 100us*500=50ms - just for counting second
int counter_to_send_packet = _50MS; // intervals betwen packets?
uint8_t flag_50ms = false; // indicates that a period of 50ms isover
uint8_t display_byte_counter_u8 = 0;

#ifdef ANDROID_HEADPHONES
//play button: tested: play button pushed for 100ms = 10 cycles of 10ms counter
int8_t play_count = 0;
//next button: tested: next button pushed for 100ms = 10 cycles of 10ms counter
#ifndef ANDROID_HEADPHONES_ONE_BUTTON
int8_t next_count = 0;
//prev button: tested: prev button pushed twise for 100ms = 2x20 cycles of 10ms counter,
uint8_t prev_count = 0;
#endif
//test: 10m between updates
uint8_t prev_count_delay = 0;
#ifdef ANDROID_HEADPHONES_ONE_BUTTON
uint8_t play_count_delay = 0;
uint8_t play_count_push = 0;
#endif
#endif


/* -- Modul Global Function Prototypes ------------------------------------- */

static void ScanCommandBytes(void);
static void DumpFullCommand(void);
static void DecodeCommand(void);
static uint8_t GetCaptureByte(void);
static void SetStateIdle(void);
static void SetStatePlay(void);
static void SetStateInitPlay(void);
static void SetStatePlayLeadIn(void);
static void SetStateTrackLeadIn(void);
static void SendDisplayBytes(void);
static void SendDisplayBytesNoCD(void);
static void SendDisplayBytesInitCD(void);
static void SendFrameByte(uint8_t byte_u8);
static void SendByte(uint8_t byte_u8);
static void EnqueueString(const uint8_t *addr PROGMEM);
static void EnqueueHex(uint8_t hexbyte_u8);
static void ResetTime(void);
static void SetStateIdleThenPlay(void);
static void SetStateTP(void);
static void SendStateIdle(void);
static void SendStatePlayLeadInEnd(void);
static void SendPacket(void);
static void SendStateInitPlayEnd(void);
static void SendStateInitPlayAnnounceCD(void);
static void SendStatePlayLeadInAnnounceCD(void);
static void SendStateTP(void);
static void printstr_p(const char *s);
static void android_buttons();
static void OutputByte(void);
static void setup_timers(void);
#define TRUE 1
#define FALSE 0


int main()
{
  Serial.begin(SERIAL_BAUDRATE);

  Init_VWCDC();
  //start in idle mode
  //SetStateIdle();
  while (1)
  {
#ifdef DISC_TRACK_NUMBER_FROM_MPD
    if (Serial.available() > 0) {
      int r = Serial.read();
      //r has new data
      if (r <= 0xFF)
      {
        //send CD No.
        if ((r & 0xF0) == 0xC0)
        {
          if (r == 0xCA)
          {
            scan = TRUE;
          }
          else if (r == 0xCB)
          {
            mix = TRUE;
          }
          else if (r == 0xCC)
          {
            SetStatePlay();
          }
          else if (r == 0xCD)
          {
            mix = FALSE;
            scan = FALSE;
            playing = FALSE;
            SetStateIdle();
          }
          else if (r == 0xCE)
          {
            mix = FALSE;
          }
          else if ((r & 0x0F) != ( disc & 0x0F))
          {
            disc = (r & 0x4F);
          }
        }
        //send TR No.
        else if (track != r)
        {
          track = r;
          ResetTime();
        }
      }
    }
#endif

    CDC_Protocol();
  }
}
// eof //

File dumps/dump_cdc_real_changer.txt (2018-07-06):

12V ON
A4 BE FE FF FF FF 6F BC                  CD: 1 track: 1   min: 0 sek: 0 mode: FF
B4 2C 0 FF FF FF FF BC                  CD: 93 track: FF   min: 0 sek: 0 mode: FF
B4 BE FE FF FF FF 6F B8                  CD: 1 track: 1   min: 0 sek: 0 mode: FF
B4 2D 0 FF FF FF FF BC                  CD: 92 track: FF   min: 0 sek: 0 mode: FF
B4 2C 0 FF FF FF FF BC                  CD: 93 track: FF   min: 0 sek: 0 mode: FF
B4 BE FE FF FF FF 2B FF                  CD: 1 track: 1   min: 0 sek: 0 mode: FF
B4 BC FE FF FF FF 6F BC                  CD: 3 track: 1   min: 0 sek: 0 mode: FF
B4 2A 0 0 0 B4 FF BC                  CD: 95 track: FF   min: FF sek: FF mode: B4
B4 29 0 FF FF FF FF BC                  CD: 96 track: FF   min: 0 sek: 0 mode: FF
B4 2E 0 FF FF FF FF BC                  CD: 91 track: FF   min: 0 sek: 0 mode: FF
B4 BE FE FF FF FF 6F BC                  CD: 1 track: 1   min: 0 sek: 0 mode: FF
B4 2C 0 FF FF FF FF BC                  CD: 93 track: FF   min: 0 sek: 0 mode: FF
B4 BE FE FF FF FF 6F BC                  CD: 1 track: 1   min: 0 sek: 0 mode: FF
B4 2B 0 FF FF FF FF BC                  CD: 94 track: FF   min: 0 sek: 0 mode: FF
B4 BE FE FF B4 FF FF BC                  CD: 1 track: 1   min: 0 sek: 4B mode: FF
B4 29 0 FF FF FF FF 7C                  CD: 96 track: FF   min: 0 sek: 0 mode: FF
B4 BE FE FF FF FF 6F BC                  CD: 1 track: 1   min: 0 sek: 0 mode: FF
B4 2E 0 FF FF FF FF BC                  CD: 91 track: FF   min: 0 sek: 0 mode: FF
B4 2D 0 FF FF FF FF BC                  CD: 92 track: FF   min: 0 sek: 0 mode: FF
B4 BE FE FF FF 0 B4 FF                  CD: 1 track: 1   min: 0 sek: 0 mode: 0
B4 BE FE FF FF FF 6F BC                  CD: 1 track: 1   min: 0 sek: 0 mode: FF
B4 2B 0 FF 0 0 BE FF                  CD: 94 track: FF   min: 0 sek: FF mode: 0
B4 BE FE FF FF FF 6F BC                  CD: 1 track: 1   min: 0 sek: 0 mode: FF
B4 29 0 FF FF FF FF BC                  CD: 96 track: FF   min: 0 sek: 0 mode: FF
B4 BE FE FF FF FF 6F BC                  CD: 1 track: 1   min: 0 sek: 0 mode: FF
B4 2D 0 FF FF FF FF BC                  CD: 92 track: FF   min: 0 sek: 0 mode: FF
B4 BE FE FF FF FF 6F BC                  CD: 1 track: 1   min: 0 sek: 0 mode: FF
B4 2C 0 FF FF FF FF BC                  CD: 93 track: FF   min: 0 sek: 0 mode: FF
B4 BE FE FF FF B4 0 FF                  CD: 1 track: 1   min: 0 sek: 0 mode: B4
B4 2A 0 FF FF FF FF BC                  CD: 95 track: FF   min: 0 sek: 0 mode: FF
B4 BE FE FF FF FF 6F BC                  CD: 1 track: 1   min: 0 sek: 0 mode: FF
B4 29 0 FF FF FF FF BC                  CD: 96 track: FF   min: 0 sek: 0 mode: FF
B4 FF BC FF FF FF FF BC                  CD: 40 track: 43   min: 0 sek: 0 mode: FF
B4 2D 0 FF FF FF FF BC                  CD: 92 track: FF   min: 0 sek: 0 mode: FF
B4 BE FE FF FF FF 6F BC                  CD: 1 track: 1   min: 0 sek: 0 mode: FF
B4 2C 0 FF FF FF BE FF                  CD: 93 track: FF   min: 0 sek: 0 mode: FF
B4 BE FE FF FF FF 6F BC                  CD: 1 track: 1   min: 0 sek: 0 mode: FF
69 BF FF DB 0 FF FF BC                  CD: 0 track: 0   min: 24 sek: FF mode: FF
B4 BE FE FF FF FF 6F BC                  CD: 1 track: 1   min: 0 sek: 0 mode: FF
B4 FF BC FF FF FF 6F BC                  CD: 40 track: 43   min: 0 sek: 0 mode: FF
B4 2E 0 FF FF FF FF 5A                  CD: 91 track: FF   min: 0 sek: 0 mode: FF
B4 2D 0 FF FF FF FF BC                  CD: 92 track: FF   min: 0 sek: 0 mode: FF
B4 BE FE FF FF 2C FF BC                  CD: 1 track: 1   min: 0 sek: 0 mode: 2C
B4 2B 0 FF FF FF FF BC                  CD: 94 track: FF   min: 0 sek: 0 mode: FF
B4 BE FE FF FF FF 6F BC                  CD: 1 track: 1   min: 0 sek: 0 mode: FF
B4 2A 0 FF FF FF FF BC                  CD: 95 track: FF   min: 0 sek: 0 mode: FF
B4 FF BC FF FF FF FF BC                  CD: 40 track: 43   min: 0 sek: 0 mode: FF
B4 BE FE FF FF FF 6F 2E                  CD: 1 track: 1   min: 0 sek: 0 mode: FF
B4 2E 0 FF FF FF FF BC                  CD: 91 track: FF   min: 0 sek: 0 mode: FF
68 40 3F FF FF 34 FF BC                  CD: FF track: C0   min: 0 sek: 0 mode: 34
A5 F7 F7 FF FF FB 7D E5                  CD: 48 track: 8   min: 0 sek: 0 mode: FB
B4 FE FF 2B FF FF FF BC                  CD: 41 track: 0   min: D4 sek: 0 mode: FF
B4 2A 0 FF FF FF FF BC                  CD: 95 track: FF   min: 0 sek: 0 mode: FF
B4 BE FE FF FF FF 6F BC                  CD: 1 track: 1   min: 0 sek: 0 mode: FF
B4 29 0 FF FF FF B4 FF                  CD: 96 track: FF   min: 0 sek: 0 mode: FF
B4 BE FE FF FF FF 6F BC                  CD: 1 track: 1   min: 0 sek: 0 mode: FF
69 7F 7F FF 16 FF FF BC                  CD: C0 track: 80   min: 0 sek: E9 mode: FF
B4 BD FE FF FF FF 6F BC                  CD: 2 track: 1   min: 0 sek: 0 mode: FF
B4 FF BC FF FF FF 6F BC                  CD: 40 track: 43   min: 0 sek: 0 mode: FF
BD FE FF FF FF 6F BC 0                  CD: 41 track: 0   min: 0 sek: 0 mode: 6F
FF BC B4 BD FE FF FF FF                  CD: 3 track: 4B   min: 42 sek: 1 mode: FF
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

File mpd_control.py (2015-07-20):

#!/usr/bin/python

#
# Created: 23.06.2013 20:00:51
#  Author: Dennis Schuett, dev.shyd.de
#  port for arduino by kovo
# 

import os
import serial
import string
import time

# bytes sent when radio keys are pressed
CDC_END_CMD = chr(0x14)
CDC_PLAY = chr(0xE4)
CDC_STOP = chr(0x10)
CDC_NEXT = chr(0xF8)
CDC_PREV = chr(0x78)
CDC_SEEK_FWD = chr(0xD8)
CDC_SEEK_RWD = chr(0x58)
CDC_CD1 = chr(0x0C)
CDC_CD2 = chr(0x8C)
CDC_CD3 = chr(0x4C)
CDC_CD4 = chr(0xCC)
CDC_CD5 = chr(0x2C)
CDC_CD6 = chr(0xAC)
CDC_CDSET = chr(0x38)
CDC_SCAN = chr(0xA0)
CDC_SFL = chr(0x60)
CDC_PLAY_NORMAL = chr(0x08)
CDC_PREV_CD = chr(0x18)


# control bytes to set the display
CMD_SCAN = chr(0xCA)
CMD_SHFFL = chr(0xCB)
CMD_PLAY = chr(0xCC)
CMD_STOPED = chr(0xCD)
CMD_SHFFL_OFF = chr(0xCE)

CD_MASK = 0xC0

cd_filename = "./last_cd"
global ser
ser = None
play_state = 'stoped';
timeout_seek = 0.5
timeout_normal = 2

# send current cd no. to radio and save it for next reboot
def set_cd_no(val):
	ser.write(val)
	fo = open(cd_filename, "wb")
	fo.write(val)
	fo.close()

# load new cd-dir
def play_cd(cd_no):
	c = ser.read()
	if c == CDC_END_CMD:
		if ser.read() == CDC_CDSET:
			play_plst(cd_no)

	elif c == CDC_CDSET: #audi concert unit sent just this no end_cmd
		play_plst(cd_no)


# play new playlst
def play_plst(plst_no):
	r = os.popen("mpc lsplaylists| grep cd" + str(plst_no)).read()
	if r != "":
		set_cd_no(chr(CD_MASK + plst_no))
		os.popen("mpc clear")
		os.popen("mpc load cd" + str(plst_no))
		os.popen("mpc play")
	else:
		print "no playlist no. {}".format(plst_no)

# init serial and last cd no. for correct radio display
def connect():
	while(1):
		try:
			global ser
			ser = serial.Serial('/dev/ttyUSB0', 9600)
			ser.timeout = timeout_normal #we need a timeout to update the track no.
			ser.writeTimeout = timeout_normal
			print play_state
			try:
				fo = open(cd_filename, "rb")
				cd = fo.read(1)
				fo.close()
				ser.write(cd)
			except:
				print "no last cd no. seting to one"
				play_cd(1)
			return
		except:
			time.sleep(2) #wait before retrying

try:
	
	#os.popen("/etc/init.d/mpd restart") #restart mpd due to alsa-equalizer
	connect()

	# read cmds from the radio and act like a cd changer
	while(1):
		try:
			c = ser.read()	
			
			if c == CDC_PLAY:
				if ser.read() == CDC_END_CMD:
					#os.popen("/etc/init.d/mpd start")
					os.popen("mpc play")
					os.popen("mpc repeat on")
					

			elif c == CDC_STOP:
				if ser.read() == CDC_END_CMD:
					os.popen("mpc pause")
					# stop service to sync current status
					#os.popen("/etc/init.d/mpd stop")

			elif c == CDC_NEXT:
				os.popen("mpc next")

			elif c == CDC_PREV:
				os.popen("mpc prev")

			elif c == CDC_SEEK_FWD:
				#ser.timeout = timeout_seek
				#while(1):
				os.popen("mpc seek +00:00:01")
				#	if ser.read() == CDC_PLAY and ser.read() == CDC_END_CMD:
				#		break
				#ser.timeout = timeout_normal

			elif c == CDC_SEEK_RWD:
				#ser.timeout = timeout_seek
				#while(1):
				os.popen("mpc seek -00:00:01")
				#	if ser.read() == CDC_PLAY and ser.read() == CDC_END_CMD:
				#		break
				#ser.timeout = timeout_normal

			elif c == CDC_CD1:
				play_cd(1)

			elif c == CDC_CD2:
				play_cd(2)

			elif c == CDC_CD3:
				play_cd(3)

			elif c == CDC_CD4:
				play_cd(4)

			elif c == CDC_CD5:
				play_cd(5)

			elif c == CDC_CD6:
				play_cd(6)

			elif c == CDC_CDSET:
				if ser.read() == CDC_END_CMD:
					fo = open(cd_filename, "rb")
					cd = fo.read(1)
					fo.close()
					if cd == chr(0xC1):
						play_plst(2)
					elif cd == chr(0xC2):
						play_plst(3)
					elif cd == chr(0xC3):
						play_plst(4)
					elif cd == chr(0xC4):
						play_plst(5)
					elif cd == chr(0xC5):
						play_plst(6)
					elif cd == chr(0xC6):
						play_plst(1)

			elif c == CDC_PREV_CD:
				if ser.read() == CDC_END_CMD:
					fo = open(cd_filename, "rb")
					cd = fo.read(1)
					fo.close()
					if cd == chr(0xC1):
						play_plst(6)
					elif cd == chr(0xC2):
						play_plst(1)
					elif cd == chr(0xC3):
						play_plst(2)
					elif cd == chr(0xC4):
						play_plst(3)
					elif cd == chr(0xC5):
						play_plst(4)
					elif cd == chr(0xC6):
						play_plst(5)
			elif c == CDC_SCAN:
				os.popen("mpc update")

			elif c == CDC_SFL:
				os.popen("mpc random on")

			elif c == CDC_PLAY_NORMAL:
				if ser.read() == CDC_END_CMD:
					os.popen("mpc play")
					os.popen("mpc random off")

			#get current track no. (radio display will be delayed up to {timeout_normal})
			mpc = os.popen("mpc |grep ] #").read()
			try:
				#if play_state is not 'playing':
				#	play_state = 'playing'
				#	ser.write(CMD_PLAY)
				mpc = mpc.split("/", 1)
				mpc = mpc[0].split("#", 1)
				tr = chr(string.atoi(mpc[1], 16))
				ser.write(tr)
			except:
				print "not playing[1]"
				play_state = 'stoped'
				#no tr number = mpd is stoped or not playing
				ser.write(CMD_STOPED)

			#get current playmode
			mpc = os.popen("mpc | grep random:").read()
			try:
				mpc = mpc.split("random: ", 1)
				if mpc[1].startswith("on"):
					ser.write(CMD_SHFFL)
				elif mpc[1].startswith("off"):
					ser.write(CMD_SHFFL_OFF)
			except:
				print "not playing[2]"
			mpc = os.popen("mpc |grep \"] #\"").read()
			try:
				mpc = mpc.split("]", 1)
				mpc = mpc[0].split("[", 1)
				if mpc[1] == "playing":
					play_state='playing'
					ser.write(CMD_PLAY)
				elif mpc [1] == "paused":
					play_state = 'paused'
					ser.write(CMD_STOPED)
			except:
				print "no playing [3]"
				play_state = 'stoped'
				ser.write(CMD_STOPED)
		except (serial.SerialException, serial.SerialTimeoutException):
			print "serial port unavailable, reconnecting..."
			ser.close()
			connect()
		except:
			raise
except (KeyboardInterrupt):
	if ser is not None:
		ser.close()
		print "port closed!"
	print "KeyboardInterrupt detected, exiting..."

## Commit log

2014-04-25 just copy from ubuntu one
    [arduino_atmega88.brd, arduino_atmega88.sch, confort_blinker.fz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]
2014-04-25 more from u1
    [4.csv, 4.ods]
2014-07-15 remove arduino_atmega88 kicad files, are in HW repo
    [arduino_atmega88.brd, arduino_atmega88.sch]
2014-07-15 readme update, add HU remote control arduino test
    [CONTROL_UNIT_TO_SW.csv, DOWN.csv, LEFT.csv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]
2014-07-16 rename audi forlder to proper VWCDCemu
    [4.csv, 4.ods, CONTROL_UNIT_TO_SW.csv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]
2014-07-16 cleaning, better sorting
    [4.csv, 4.ods, CONTROL_UNIT_TO_SW.csv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]
2014-07-16 Added wire diagram
2014-11-04 remove unneeded files
    [ols_100khz_dump_radio_to_cluster_2.olp.ols.csv, ols_100khz_dump_radio_to_cluster_2.olp.ols.ods]
2014-11-05 spi/nospi version so code can be included in VWCDemu project
2015-02-23 Update cdc.ino
    just note to fix using delay () in main loop
    [cdc.ino]
2015-03-11 initial work on CDC arduino libraries, not done yet
2015-03-12 RDS dumps from audi concert
    [rds_100khz.csv]
2015-03-16 version from vincent ported for seeduino, ported for atmegax8 family, arduino duemilanove in my case
2015-03-16 PREVIOUS button roll to track 99
2015-03-19 disable ovf interupt on timer0 to disable millis() on arduino board
2015-03-27 arduino pins description
2015-03-27 switch to serial output/input, fixies
2015-04-01 vwcdpic dumps
    [dump_avr_port.txt, dump_vwcdpic_v2.txt]
2015-04-10 timer2 prescaler 64 for 700us timing,CD numbers comments typo
2015-06-01 arduino port of shyd mpd control plus tweek for my audi concert1/chorus1 head unit
2015-06-01 initial bluetooth support for BLK-MD-SPK-B board
2015-06-01 rename to make arduino sw happy :)
2015-06-02 arduino port of avr version of k9spud vwcdpic with shyd.de mpd control script support
2015-06-03 mpd control script based on shyd.de version supporting vwcdpic PRJC player serial command
2015-06-12 revert MPD_CONTROL_WITH_MPC bullshit ... and instead of it make mpc_control.py calculate this from last_cd file
    [cdc_arduino_ported_k9spud_vwcdpic.ino, mpd_control.py, mpd_control_vwcdpic.py]
2015-07-13 changed pin names to port IO - diferent packages-difrent pins
2015-07-14 revert some unused code from testing
    [cdc_arduino_ported_k9spud_vwcdpic.ino]
2015-08-06 2x8-bit timers version
2015-08-13 donate button by pledgie
2015-10-08 fixed compile error ‘Serial’ was not declared in this scope on atmegaXXX
    [cdc_arduino_ported_k9spud_vwcdpic_just_8bit_timers.ino]
2015-10-13 move to standalone repository
    [dump_avr_port.txt, dump_vwcdpic_v2.txt]
2016-03-23 formating, minutes, seconds initialize with zero value, better place of resettime after change of CD and track
    [cdc_arduino_ported_k9spud_vwcdpic_just_8bit_timers.ino]
2016-03-29 match changes to 8bit timer version, which make it works on RCD300
2016-03-31 pin swap dataclk and datain, to match SPI clk data pins, android prev/play/next are on pin 7,6,5 to have it together,android support is somehow broken now :(
    [cdc_arduino_ported_k9spud_vwcdpic_just_8bit_timers.ino, functions.ino]
2016-09-28 swap data/clk line pb4/pb5 to make it same as in cdc_arduino_ported_k9spud_vwcdpic.ino
    [cdc_arduino_ported_k9spud_vwcdpic_just_8bit_timers.ino]
2016-09-28 change clk/datain pins in cd emeulator to match SPI pins in shyd version, bor easy HW development
2016-09-29 pb5 is arduino pin 13
2018-05-29 fix #6, start in idle should be only when mpd support is activated (maybe bluetooth???)
    [cdc_arduino_ported_k9spud_vwcdpic.ino]
2018-06-28 fix #8, TP-INFO button pushed
    [cdc_arduino_ported_k9spud_vwcdpic.ino, cdc_arduino_ported_k9spud_vwcdpic_just_8bit_timers.ino, functions.ino]
2018-07-06 remove useless dumps
    [dump_avr_port.txt, dump_vwcdpic_v2.txt]
2018-07-06 dumps from real changer
    [dump_cdc_real_changer.txt, dump_cdc_real_changer_real_radio_audi_concert1.txt]
2019-01-17 final fix for attiny85! finaly! :D5
    [cdc_arduino_ported_k9spud_vwcdpic_just_8bit_timers.ino]
2019-01-17 fix comment about used pins
    [radio_emulator.ino]
2019-01-18 fixed comment for attiny85, digispark tested and works!
    [cdc_arduino_ported_k9spud_vwcdpic_just_8bit_timers.ino]
2019-03-25 port for arduino mega (ATMEGA2560)
2020-04-01 revert part of c9bc5cce96d51d5ce315a0b47d3cb876d2d974aa
    [cdc_arduino_ported_k9spud_vwcdpic.ino]
2020-04-01 commented includes, no neet this in arduino, I leave it if someone wanne compile it without arduinoide
2020-04-01 do not send empty strings to uart
2020-04-01 TIMER1_CAPT_vect formating
2020-04-01 TIMER1_OVF_vect formating
2020-04-01 TIMER0_COMPA_vect formating
2020-04-01 TIMER2_COMPA_vect formating
2020-04-01 TIMER2_COMPA_vect fixies
2020-04-01 timer2 fixies
2020-04-01 correct pin definition
2020-04-01 safe SPI timing on output pins
2020-04-01 single timer version-unfinished!
2020-07-02 missing breaks in switch()
    [functions.ino]
2020-07-13 Revert "missing breaks in switch()"
    This reverts commit d754e8320e7db1d1858366a9e0ef85fcda8f8fea.
    [functions.ino]
2020-07-13 Revert "missing breaks in switch()"
    This reverts commit 5401889777d2c840d914cabefa656177a234658a.
    [functions.ino]
2020-07-13 notes about breaks in switch()
2020-09-29 fix output pins comment
    [cdc_arduino_ported_k9spud_vwcdpic_just_8bit_timers.ino]
2020-09-29 use arduinos delayMicroseconds()
2020-10-06 move hw part frm hw repository in this repository
    [atmegax8_with_BM20-2018-02-13-11-43-26.sch, atmegax8_with_BM20-2018-02-23-22-28-24.sch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]
2020-10-06 move more functions to functions.ino and create timers.ino, more formating, changed timer to 10us and using 10us tick for timing output CLK
2020-11-10 bm20 version update to 328PB
    [atmegax8_with_BM20.kicad_pcb]
2020-11-10 interactive bom
2020-11-10 schematics new format
    [atmegax8_with_BM20.kicad_sch]
2020-11-14 link to interactive bom in readme
2020-11-26 fixes in HW for F6188
    [atmegax8_with_bluetooth.kicad_pcb, atmegax8_with_bluetooth.kicad_sch]
2020-11-27 disable serial.print used for debug
2020-11-27 disabled input filters,for now
    [atmegax8_with_BM20.kicad_pcb, atmegax8_with_BM20.kicad_sch]
2021-04-11 revert sendpacket() to propper location
    [cdc_arduino_ported_k9spud_vwcdpic.ino]
2021-05-25 fix timer2 bug
2021-05-29 timers 3or4 for PB versions, timers config fixies, serial/serial1 output for PBs
    [cdc_arduino_ported_k9spud_vwcdpic.ino, functions.ino]
2021-11-27 correct value for mic resistors
    [atmegax8_with_bluetooth.kicad_pcb, atmegax8_with_bluetooth.kicad_sch]
2021-11-27 fix wrong pinout selected!
    [cdc_arduino_ported_k9spud_vwcdpic.ino]
2022-04-29 schematics in pdf
2026-05-09 Fix cdButtonPushed case 6, Do_CD2 arg, ATmega8 ISR ==/= bug; update dumps.md
    Agent-Logs-Url: https://github.com/tomaskovacik/vwcdavr/sessions/397b4839-dc44-40a8-8b4e-6f8bb0b28d41
    [cdc_arduino_ported_k9spud_vwcdpic.ino, cdc_arduino_ported_k9spud_vwcdpic_with_BK3254.ino, functions.ino]
